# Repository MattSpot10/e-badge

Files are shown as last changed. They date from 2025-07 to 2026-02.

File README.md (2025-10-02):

# eBadge

**eBadge** is a customizable, hackable electronics badge designed for students to explore, build, and learn throughout their academic journey. It’s more than just a badge—it's a personal electronics lab, wearable project canvas, and long-term learning tool.

## Features

- Custom PCB with microcontroller 
- Modular peripherals: LEDs, sensors, buttons, displays, etc.
- Fully programmable with open-source firmware
- Designed for learning — from blinking LEDs to building full apps
- Battery-powered & portable — perfect for hacking on the go

## What’s in This Repo?

```bash
e-badge/
├── docs/           # Project documentation, setup guides, and images
├── hardware/       # Schematics, PCB layouts, BOMs, and 3D models
├── firmware/       # Embedded code for the badge's microcontroller
├── software/       # Host-side apps, test tools, or configurators
├── assets/         # Logos, badge graphics, and artwork
├── test/           # Scripts for testing hardware and firmware
├── LICENSE-CODE
├── LICENSE-HARDWARE
├── LICENSE-DOCS
├── README.md
└── .gitignore
```
## License

- **Hardware** – [CERN-OHL-S v2.0](./LICENSE-HARDWARE)
- **Firmware/Code** – [MIT License](./LICENSE-CODE)
- **Docs & Assets** – [CC BY-SA 4.0](./LICENSE-DOCS)

## Contributors

- Nathan Jack (jackn@byui.edu)
- Lynn Watson (watsonl@byui.edu)
- Jason Allred (allredjas@byui.edu)
- Richard Grimmett (grimmettr@byui.edu)
- Carl Gibbons (gibbonsc@byui.edu)
- Craig Lindstrom (lindstromc@byui.edu)
- Gary Godderidge (godderidgeg@byui.edu)
- Matt Manley (manleym@byui.edu)

# TODO (Senior project, delete when done)
- Fix screen connector
	- Use LCSC part C11086

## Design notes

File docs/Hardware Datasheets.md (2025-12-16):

| Part | Part Value | Datasheet link |
|---|---|---|
| Accelormeter | MMA8452QR1_C11360 | [Link](https://lcsc.com/datasheet/lcsc_datasheet_2405281404_NXP-Semicon-MMA8452QR1_C11360.pdf) |
| Buzzer | MLT-5020 | [Link](https://lcsc.com/datasheet/lcsc_datasheet_2410121451_Jiangsu-Huaneng-Elec-MLT-5020_C94598.pdf) |
| Charging Manager | TP4056 | [Link](https://www.lcsc.com/datasheet/lcsc_datasheet_1809261820_TOPPOWER-Nanjing-Extension-Microelectronics-TP4056-42-ESOP8_C16581.pdf) |
| MCU | ESP32-S3-Mini-1-N8  | [Link](https://www.espressif.com/sites/default/files/documentation/esp32-s3-mini-1_mini-1u_datasheet_en.pdf) |
| Joystick | 2765 | [Link](https://www.adafruit.com/product/2765) |
| RGB LED | RS-3535MWAM | [Link](https://lcsc.com/datasheet/lcsc_datasheet_2410121728_Foshan-NationStar-Optoelectronics-RS-3535MWAM_C842778.pdf) |
| SD Card | TF PUSH | [Link](https://lcsc.com/datasheet/lcsc_datasheet_2504101957_SHOU-HAN-TF-PUSH_C393941.pdf) |
| USB-Serial Chip  | CP2102N-A02-GQFN28R | [Link](https://lcsc.com/datasheet/lcsc_datasheet_2304140030_SKYWORKS-SILICON-LABS-CP2102N-A02-GQFN28R_C964632.pdf) |
| Adressable LEDs  | C22371528 | [Link](https://item.szlcsc.com/datasheet/WS2813B-2121/23859548.html) |

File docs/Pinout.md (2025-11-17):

## Pinout for BYUI e-Badge V3.0

| Name | No. | Type  | In Use | Description | Full Function List |
|---|---|---|---|---|---|
| GND | 1,2,42,43,46-65 | P | | | GND |
| 3V3 | 3 | P | | | Powersupply |
| IO0 | 4 | I/O/T |  Y | Strapping | RTC_GPIO0, GPIO0 |
| IO1 | 5 | I/O/T |  X | Joystick X  | RTC_GPIO1, GPIO1,TOUCH1,ADC1_CH0 |
| IO2 | 6 | I/O/T |  X | Joystick Y  | RTC_GPIO2, GPIO2,TOUCH2,ADC1_CH1 |
| IO3 | 7 | I/O/T |  X | Strapping; SD CS | RTC_GPIO3, GPIO3,TOUCH3,ADC1_CH2 |
| IO4 | 8 | I/O/T |  Y | B LED | RTC_GPIO4, GPIO4,TOUCH4,ADC1_CH3 |
| IO5 | 9 | I/O/T |  Y | G LED | RTC_GPIO5, GPIO5,TOUCH5,ADC1_CH4 |
| IO6 | 10 | I/O/T |  Y | R LED | RTC_GPIO6, GPIO6,TOUCH6,ADC1_CH5 |
| IO7 | 11 | I/O/T |  Y | Addr LEDs | RTC_GPIO7, GPIO7,TOUCH7,ADC1_CH6 |
| IO8 | 12 | I/O/T |  Y | Minibadge CLK | RTC_GPIO8, GPIO8,TOUCH8,ADC1_CH7,SUBSPICS1 |
| IO9 | 13 | I/O/T |  X | Display CS  | RTC_GPIO9, GPIO9,TOUCH9,ADC1_CH8,FSPIHD,SUBSPIHD |
| IO10 | 14 | I/O/T |  X | SPI2 MISO | RTC_GPIO10, GPIO10,TOUCH10,ADC1_CH9,FSPICS0,FSPIIO4, SUBSPICS0 |
| IO11 | 15 | I/O/T |  X | SPI2 MOSI | RTC_GPIO11, GPIO11,TOUCH11,ADC2_CH0,FSPID,FSPIIO5,SUBSPID |
| IO12 | 16 | I/O/T |  X | SPI2 CLK | RTC_GPIO12, GPIO12,TOUCH12,ADC2_CH1,FSPICLK,FSPIIO6, SUBSPICLK |
| IO13 | 17 | I/O/T |  X | Display DC  | RTC_GPIO13, GPIO13,TOUCH13,ADC2_CH2,FSPIQ,FSPIIO7,SUBSPIQ |
| IO14 | 18 | I/O/T |  Y | L | RTC_GPIO14, GPIO14,TOUCH14,ADC2_CH3,FSPIWP,FSPIDQS, SUBSPIWP |
| IO15 | 19 | I/O/T |  Y | R | RTC_GPIO15, GPIO15,U0RTS,ADC2_CH4,XTAL_32K_P |
| IO16 | 20 | I/O/T |  Y | D | RTC_GPIO16, GPIO16,U0CTS,ADC2_CH5,XTAL_32K_N |
| IO17 | 21 | I/O/T |  Y | U | RTC_GPIO17, GPIO17,U1TXD,ADC2_CH6 |
| IO18 | 22 | I/O/T |  Y | B | RTC_GPIO18, GPIO18,U1RXD,ADC2_CH7,CLK_OUT3 |
| IO19 | 23 | I/O/T |  X | USB- | RTC_GPIO19,GPIO19,U1RTS,ADC2_CH8,CLK_OUT2, USB_D- |
| IO20 | 24 | I/O/T |  X | USB+ | RTC_GPIO20,GPIO20,U1CTS,ADC2_CH9,CLK_OUT1, USB_D+ |
| IO21 | 25 | I/O/T |  X | I2C SCL | RTC_GPIO21, GPIO21 |
| IO26^{b} | 26 | I/O/T |  X | SPI FLASH | SPICS1, GPIO26 |
| IO47 | 27 | I/O/T |  X | I2C SDA | SPICLK_P_DIFF, GPIO47,SUBSPICLK_P_DIFF |
| IO33 | 28 | I/O/T |  X | SPI FLASH | SPIIO4, GPIO33,FSPIHD,SUBSPIHD |
| IO34 | 29 | I/O/T |  X | SPI FLASH | SPIIO5, GPIO34,FSPICS0,SUBSPICS0 |
| IO48 | 30 | I/O/T |  X | Display RST | SPICLK_N_DIFF, GPIO48,SUBSPICLK_N_DIFF |
| IO35 | 31 | I/O/T |  X | SPI FLASH | SPIIO6, GPIO35,FSPID,SUBSPID |
| IO36 | 32 | I/O/T |  X | SPI FLASH | SPIIO7, GPIO36,FSPICLK,SUBSPICLK |
| IO37 | 33 | I/O/T |  X | SPI FLASH | SPIDQS, GPIO37,FSPIQ,SUBSPIQ |
| IO38 | 34 | I/O/T |  Y | A | GPIO38,FSPIWP,SUBSPIWP |
| IO39 | 35 | I/O/T |  X | JTAG | MTCK,GPIO39,CLK_OUT3,SUBSPICS1 |
| IO40 | 36 | I/O/T |  X | JTAG | MTDO,GPIO40,CLK_OUT2 |
| IO41 | 37 | I/O/T |  X | JTAG; C LED | MTDI,GPIO41,CLK_OUT1 |
| IO42 | 38 | I/O/T |  X | JTAG; Buzzer| MTMS,GPIO42 |
| TXD0 | 39 | I/O/T |  X | UART | U0TXD,GPIO43,CLK_OUT1 |
| RXD0 | 40 | I/O/T |  X | UART | U0RXD,GPIO44,CLK_OUT2 |
| IO45 | 41 | I/O/T |  X | Strapping | GPIO45 |
| IO46 | 44 | I/O/T |  X | Strapping | GPIO46 |
| EN | 45 | I | | | High:on,enablesthechip. <br> Low:off,thechippowersoff. <br> Note:DonotleavetheENpinfloating. |

b For modules with ordering codes ending with -N4R2, IO26 connects to the embedded PSRAM and is not
available for other uses
<br>Y = taken
<br>X = Taken, but exposed



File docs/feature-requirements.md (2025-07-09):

# eBadge Featureset

### MCU Features
* Wi-Fi/Bluetooth Capable
* JTAG single step debugging
* Dual Core (Defaults to Single Core)
* Supports MicroPython, Arduino IDE and RTOS!

### On-board Peripherals
* SPI Multicolor Screen (refresh >= 30 Hz)
* 6X Buttons with pull-down resistor configuration
* 2 LEDs
* 1 Tri-colored LED
* Speaker
* SD Card Slot
* Open slot of analog stick from Adafruit

### Interfaces
* 4pin JST SH/Grove/Stemma Connector 
* 4pin JST PH/mini-grove/Stemma QT connector
* 2X Minibadge Connectors
* 9X genereic Female Headers
* 10X exposed multipurpose pins

### Additional Features
* Detailed Silk Screen
* Battery hook in + charging circuitry
* Accelerometer

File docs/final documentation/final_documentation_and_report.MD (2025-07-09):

# BYU-Idaho Dev Board Badge  
**Senior Capstone Project – ECEN 499 S25**

## Team Members  
- **Carson Bush** – [bus21005@byui.edu](mailto:bus21005@byui.edu)  
- **Getu Keno** – [haw16019@byui.edu](mailto:haw16019@byui.edu)  
- **Ammon Edwards** – [edw20012@byui.edu](mailto:edw20012@byui.edu)  
- **Danny Tolman** – [ken17002@byui.edu](mailto:ken17002@byui.edu)  
- **Everett Buttars** – [tol21004@byui.edu](mailto:tol21004@byui.edu)

## Faculty Sponsors  
- **Matt Manley (Lead)** – BYUI CSE Dept – [manleym@byui.edu](mailto:manleym@byui.edu)  
- **Jason Allred** – BYUI CSE Dept – [allredjas@byui.edu](mailto:allredjas@byui.edu)  
- **Richard Grimmett** – BYUI CSE Dept – [grimmettr@byui.edu](mailto:grimmettr@byui.edu)  
- **Lynn Watson** – BYUI CSE Dept – [watsonl@byui.edu](mailto:watsonl@byui.edu)  
- **Nathan Jack** – BYUI CSE Dept – [nathanjack@byui.edu](mailto:nathanjack@byui.edu)

## Project Repository Overview  
This repository contains all design files, documentation, and resources for the BYU-Idaho Dev Board Badge senior project. The board is a wearable, student-focused development platform designed for educational use across the Electrical and Computer Engineering and Computer Science programs.

### Key Features  
- Wearable Minibadge-compatible form factor  
- Support for both C and MicroPython environments  
- Designed for multi-semester reuse  
- Educational ecosystem compatibility (Grove, STEMMA, SAO)  
- Rechargeable battery support with USB-C charging  
- Standards-based I²C, SPI, and USB interfaces

---

## Included in This Repository  

### 📁 Final Deliverables  
- Final Written Report (with Bill of Materials)  
- Final Oral Presentation – Slides & Video  
- Final Project Poster  
- Executive Summaries  
- Weekly Progress Reports (WIGs)

### 📁 Design Files  
- KiCad Schematic & PCB Layout  
- Pinout Diagram  
- 3D Board Render (optional)  
- Firmware Prototypes (MicroPython / C)  
- Machine Learning Data & Code (Tomato Classification Project)  
- RGB LED Control Documentation

### 📁 Testing & Validation  
- Testing Code  
- Demonstration Scripts  
- Data Analysis Tools

---

## Usage Notes  
To properly view relative file links and embedded diagrams, open this repository in a Markdown-rendering environment (such as GitHub, GitLab, or a Markdown viewer). For local file viewing, Chrome or Firefox are recommended. **Do not use Edge**, as it does not reliably resolve local relative paths.

---

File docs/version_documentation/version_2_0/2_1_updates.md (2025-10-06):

# Version 2.1 Updates

<details>
<summary>Buzzer Circuitry Fix</summary>
<br>

The buzzer circuitry went straight into the GPIO pin.
</details>

<details>
<summary>Green LED Flashing</summary>
<br>
</details>

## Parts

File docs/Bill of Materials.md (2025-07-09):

| Datasheet | On Board Reference | Qty | Value | Footprint |
| --- | --- | --- | --- | --- |
| [Piezo Buzzer](https://lcsc.com/product-detail/Buzzers_MLT-5020_C94598.html) | BUZZER1 | 1 | MLT-5020 | lcsc-lib:BUZ-SMD_L5.0-W5.5-P4.60 |
| [Cap](https://www.lcsc.com/datasheet/lcsc_datasheet_2304140030_Samsung-Electro-Mechanics-CL10A106MA8NRNC_C96446.pdf) | C1,C5,C6,C7,C12,C13 | 6 | 10uF | PCM_JLCPCB:C_0603 |
| [Cap](https://www.lcsc.com/datasheet/lcsc_datasheet_2211101700_YAGEO-CC0603KRX7R9BB104_C14663.pdf) | C2,C10,C11,C14,C24,C25  | 6 | 100nF | PCM_JLCPCB:C_0603 |
| [Cap](https://www.lcsc.com/datasheet/lcsc_datasheet_2304140030_Samsung-Electro-Mechanics-CL05A105KA5NQNC_C52923.pdf) | C3,C4,C8,C9,C15,C16,C17 | 7 | 1uF | PCM_JLCPCB:C_0402 |
| [Cap](https://www.lcsc.com/datasheet/lcsc_datasheet_2304140030_Samsung-Electro-Mechanics-CL10A105KB8NNNC_C15849.pdf) | C18,C19,C20,C21,C22,C23 | 6 | 1uF | PCM_JLCPCB:C_0603 |
| [Cap](https://www.lcsc.com/datasheet/lcsc_datasheet_2304140030_Samsung-Electro-Mechanics-CL10A475KO8NNNC_C19666.pdf) | C26 | 1 | 4.7uF | PCM_JLCPCB:C_0603 |
| [SD Card](https://lcsc.com/product-detail/Connector-Card-Sockets_SHOU-HAN-SHOU-HAN-TFDeck-TF-Deck_C393941.html) | SD Card | 1 | TF PUSH | lcsc-lib:TF-SMD_TF-PUSH |
| [JST PH](https://lcsc.com/product-detail/_JST_B4B-PH-SM4-TB-LF-SN_B4B-PH-SM4-TB-LF-SN_C160354.html) | CN1 | 1 | B4B-PH-SM4-TB (LF)(SN) | lcsc-lib:CONN-SMD_B4B-PH-SM4-TB-LF-SN |
| [Red LED](https://www.lcsc.com/datasheet/lcsc_datasheet_1810231112_Hubei-KENTO-Elec-KT-0603R_C2286.pdf) | D1,D10 | 2 | Red | PCM_JLCPCB:D_0603 |
| [Surge Protector](https://lcsc.com/product-detail/New-Arrivals_Leshan-Radio-LESD5D5-0CT1G_C383211.html) | D2,D3,D4,D6,D7,D8 | 6 | LESD5D5.0CT1G | lcsc-lib:SOD-523_L1.2-W0.8-LS1.6-BI |
| [Schottky](https://wmsc.lcsc.com/wmsc/upload/file/pdf/v2/lcsc/2308281443_hongjiacheng-B0520W_C7502707.pdf) | D5,D9,D11 | 3 | B0520W | PCM_JLCPCB:D_SOD-123 |
| [LED](https://www.lcsc.com/datasheet/lcsc_datasheet_1806151820_Hubei-KENTO-Elec-KT-0805G_C2297.pdf) | D12 | 1 | Green | PCM_JLCPCB:D_0805 |
| [USB-C](https://atta.szlcsc.com/upload/public/pdf/source/20220920/0EF8F885FCCEA71F60E9E85152155021.pdf) | J1,J2 | 2 | Connector, USB-TYPE-C-16P | PCM_JLCPCB:TYPE-C-SMD_HX-TYPE-C-16PIN |
| [Ribbon Cable](https://www.lcsc.com/datasheet/lcsc_datasheet_2504101957_JUSHUO-AFC01-S12FCA-00_C262661.pdf) | J3 | 1 | ~ | lcsc-lib:FPC-SMD_AFC01-S12FCA-00 |
| [RGB LED](https://lcsc.com/product-detail/Light-Emitting-Diodes-LED_Foshan-NationStar-Optoelectronics-RS-3535MWAM_C842778.html) | LED1 | 1 | RS-3535MWAM | lcsc-lib:LED-ARRAY-SMD_L3.7-W3.5-P1.10-TL |
| [Mini-Badge*](https://github.com/BYU-I-eBadge/minibadge/blob/master/README.md) | MB1,MB2 | 2 | MiniBadge_Full | minibadge:MiniBadge_Full_NoEdges |
| [Battery JST PH](https://lcsc.com/product-detail/PH-Connectors_PH-2A_C2319.html) | P1 | 1 | PH-2A_C2319 | lcsc-lib:CONN-TH_2P-P2.00_PH-2A_C2319 |
| [Transistor](https://www.lcsc.com/datasheet/lcsc_datasheet_2303221100_Jiangsu-Changjing-Electronics-Technology-Co---Ltd--SS8050-RANGE-200-350_C2150.pdf) | Q1,Q2 | 2 | SS8050 200-350 | PCM_JLCPCB:Q_SOT-23 |
| [MOSFET](https://wmsc.lcsc.com/wmsc/upload/file/pdf/v2/lcsc/2308281515_hongjiacheng-HL2301A_C7420344.pdf) | Q3 | 1 | HL2301A | PCM_JLCPCB:Q_SOT-23 |
| [Resistor](https://www.lcsc.com/datasheet/lcsc_datasheet_2206010216_UNI-ROYAL-Uniroyal-Elec-0402WGF0000TCE_C17168.pdf) | R1,R11,R12,R15,R16 | 5 | 0Ω | PCM_JLCPCB:R_0402 |
| [Resistor](https://www.lcsc.com/datasheet/lcsc_datasheet_2206010045_UNI-ROYAL-Uniroyal-Elec-0402WGF5101TCE_C25905.pdf) | R2,R3,R4,R5,R6,R19 | 6 | 5.1kΩ | PCM_JLCPCB:R_0402 |
| [Resistor](https://www.lcsc.com/datasheet/lcsc_datasheet_2206010100_UNI-ROYAL-Uniroyal-Elec-0402WGF2202TCE_C25768.pdf) | R7 | 1 | 22kΩ | PCM_JLCPCB:R_0402 |
| [Resistor](https://www.lcsc.com/datasheet/lcsc_datasheet_2206010100_UNI-ROYAL-Uniroyal-Elec-0402WGF4702TCE_C25792.pdf) | R8 | 1 | 47kΩ | PCM_JLCPCB:R_0402 |
| [Resistor](https://www.lcsc.com/datasheet/lcsc_datasheet_2206010216_UNI-ROYAL-Uniroyal-Elec-0402WGF1001TCE_C11702.pdf) | R9,R25 | 2 | 1kΩ | PCM_JLCPCB:R_0402 |
| [Resistor](https://www.lcsc.com/datasheet/lcsc_datasheet_2411221126_UNI-ROYAL-Uniroyal-Elec-0402WGF1002TCE_C25744.pdf) | R10,R13,R14,R17 | 4 | 10kΩ | PCM_JLCPCB:R_0402 |
| [Resistor](https://www.lcsc.com/datasheet/lcsc_datasheet_2205311900_UNI-ROYAL-Uniroyal-Elec-0402WGF1000TCE_C25076.pdf) | R18,R20 | 2 | 100Ω | PCM_JLCPCB:R_0402 |
| [Resistor](https://www.lcsc.com/datasheet/lcsc_datasheet_2205311900_UNI-ROYAL-Uniroyal-Elec-0402WGF470JTCE_C25118.pdf) | R21,R22 | 2 | 47Ω | PCM_JLCPCB:R_0402 |
| [Potentiometer](https://lcsc.com/product-detail/Precision-Potentiometer_10KR_C118954.html) | R23 | 1 | 3296W-1-103 | lcsc-lib:RES-ADJ-TH_3P-L10.0-W10.0-P2.50-L |
| [Resistor](https://www.lcsc.com/datasheet/lcsc_datasheet_2206010100_UNI-ROYAL-Uniroyal-Elec-0402WGF1003TCE_C25741.pdf) | R24 | 1 | 100kΩ | PCM_JLCPCB:R_0402 |
| [Resistor](https://www.lcsc.com/datasheet/lcsc_datasheet_2206010045_UNI-ROYAL-Uniroyal-Elec-0402WGF2201TCE_C25879.pdf) | R26 | 1 | 2.2kΩ | PCM_JLCPCB:R_0402 |
| [Resistor](https://www.lcsc.com/datasheet/lcsc_datasheet_2206010045_UNI-ROYAL-Uniroyal-Elec-0603WAF1002T5E_C25804.pdf) | R27-R38 | 12  | 10kΩ | PCM_JLCPCB:R_0603 |
| [Resistor](https://www.lcsc.com/datasheet/lcsc_datasheet_2206010116_UNI-ROYAL-Uniroyal-Elec-0603WAF4701T5E_C23162.pdf) | R39,R40 | 2 | 4.7kΩ | PCM_JLCPCB:R_0603 |
| [Joy Stick*](https://www.adafruit.com/product/444) | S1 | 1 | 2765 | AdafruitJoystick:SW_2765 |
| [set/reset Buttons](https://lcsc.com/product-detail/Tactile-Switches_XUNPU-TS-1088-AR02016_C720477.html) | SW1,SW2 | 2 | TS-1088-AR02016 | lcsc-lib:SW-SMD_L3.9-W3.0-P4.45 |
| [On/Off Switch](https://lcsc.com/product-detail/Slide-Switches_G-Switch-MK-12C02-G020_C963206.html) | SW3 | 1 | SK-12F04-G050 | lcsc-lib:SW-TH_G-SWITCH_SK-12F04-G050 |
| [Push Buttons](https://lcsc.com/product-detail/Tactile-Switches_SHOU-HAN-TS665CJ_C393938.html) | SW4,SW5,SW6,SW7,SW8,SW9 | 6 | TS665CJ | lcsc-lib:SW-TH_4P-L6.0-W6.0-P4.50-LS6.5 |
| [MCU](https://www.espressif.com/sites/default/files/documentation/esp32-s3-mini-1_mini-1u_datasheet_en.pdf) | U1 | 1 | ESP32-S3-MINI-1-N8 | RF_Module:ESP32-S2-MINI-1 |
| [Voltage Regulator](https://lcsc.com/product-detail/Linear-Voltage-Regulators-LDO_onsemi-NCP167BMX330TBG_C892227.html) | U2 | 1 | NCP167BMX330TBG | lcsc-lib:XDFN-4_L1.0-W1.0-P0.65-BL-EP |
| [UART-USB](https://www.silabs.com/documents/public/data-sheets/cp2102n-datasheet.pdf) | U3 | 1 | CP2102N-A02-GQFN28R | lcsc-lib:QFN-28_L5.0-W5.0-P0.50-TL-EP3.3 |
| [Battery Charger](https://www.lcsc.com/datasheet/lcsc_datasheet_1809261820_TOPPOWER-Nanjing-Extension-Microelectronics-TP4056-42-ESOP8_C16581.pdf) | U4 | 1 | TP4056 | PCM_JLCPCB:ESOP-8_L4.9-W3.9-P1.27-LS6.0-BL-EP |
| [2 Pin Female Header](https://lcsc.com/product-detail/Female-Headers_XUNPU-FH2-54-09-02PZD_C7500771.html) | U5,U7,U10,U13,U17,U19 | 6 | FH2.54-09-02PZD | lcsc-lib:HDR-TH_2P-P2.54-V-M-5 |
| [JST-SH](https://lcsc.com/product-detail/Wire-To-Board-Connector_Megastar-ZX-SH1-0-4PWT_C7430446.html) | U6 | 1 | ZX-SH1.0-4PWT | lcsc-lib:CONN-SMD_4P-P1.00_MEGASTAR_ZX-SH1.0-4PWT |
| [3 Pin Female Header](https://lcsc.com/product-detail/Female-Headers_XUNPU-FH2-54-09-03PZD_C7500772.html) | U8,U9,U12 | 3 | FH2.54-09-03PZD | lcsc-lib:HDR-TH_3P-P2.54-V-F |
| [4 Pin Female Header](https://lcsc.com/product-detail/Female-Headers_XUNPU-FH2-54-09-03PZD_C7500772.html) | U11,U14,U15,U16 | 4 | FH2.54-09-04PZD | lcsc-lib:HDR-TH_4P-P2.54-V-F |
| [Accelerometer](https://lcsc.com/product-detail/Motion-Sensors-Accelerometers_FREESCALE_MMA8452QR1_MMA8452QR1_C11360.html) | U18 | 1 | MMA8452QR1_C11360 | lcsc-lib:QFN-16_L3.0-W3.0-P0.50-TL_MMA8452QR1 |
| | | | | |
\* Item is used for footprint and not included in final BoM

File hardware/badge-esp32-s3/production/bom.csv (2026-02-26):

Designator | Footprint | Quantity | Value | LCSC Part #
AL1, AL10, AL11, AL12, AL13, AL14, AL15, AL16, AL17, AL18, AL19, AL2, AL20, AL21, AL22, AL23, AL24, AL3, AL4, AL5, AL6, AL7, AL8, AL9 | LED-SMD_6P-L2.2-W2.2-TL-1 | 24 | ~ | C22371528
BUZZER1 | BUZ-SMD_L5.0-W5.5-P4.60 | 1 | MLT-5020 | C94598
C1, C12, C13, C5, C6, C7 | C_0603 | 6 | 10uF | C96446
C10, C11, C25, C34, C35, C36 | C_0402 | 6 | 100nF | C1525
C14, C2 | C_0603 | 2 | 100nF | C14663
C15, C16, C3, C32, C33, C4, C8, C9 | C_0402 | 8 | 1uF | C52923
C17, C27 | C0805 | 2 | 10uF
C18, C19, C20, C21, C22, C23 | C_0603 | 6 | 1uF | C15849
C26 | C_0603 | 1 | 4.7uF | C19666
C28, C37 | C0603 | 2 | TMK107BBJ106MA-T | C386081
C29, C30, C31 | C0805 | 3 | 22uF
CARD1 | TF-SMD_TF-PUSH | 1 | TF PUSH | C393941
CN1 | CONN-SMD_B4B-PH-SM4-TB-LF-SN | 1 | B4B-PH-SM4-TB (LF)(SN) | C160354
D1, D14 | D_0603 | 2 | Red | C2286
D11, D5, D9 | D_SOD-123 | 3 | B0520W | C7502707
D12 | D_0805 | 1 | Green | C2297
D13 | SMA_L4.5-W2.6-LS5.1-RD | 1 | SMAJ7.0A
D2, D3, D4, D6, D7, D8 | SOD-523_L1.2-W0.8-LS1.6-BI | 6 | LESD5D5.0CT1G | C5199850
J1, J2 | TYPE-C-SMD_HX-TYPE-C-16PIN | 2 | Connector, USB-TYPE-C-16P | C2927039
J11 | PinSocket_2x03_P2.54mm_Vertical | 1 | Conn_02x03_Odd_Even | C541853
J12, J14, J15, J5 | PinSocket_1x02_P2.54mm_Vertical | 4 | Conn_01x02_Socket | C7499322
J13, J6 | PinSocket_1x04_P2.54mm_Vertical | 2 | Conn_01x04_Socket | C2718488
J3, J9 | PinSocket_2x06_P2.54mm_Vertical | 2 | Conn_02x06_Odd_Even | C5307342
J4 | PinSocket_2x15_P2.54mm_Vertical | 1 | Conn_02x15_Odd_Even | C7499350
J7, J8 | PinSocket_1x08_P2.54mm_Vertical | 2 | Conn_01x08_Socket | C42385698
L3 | IND-SMD_L4.0-W4.0_XEL4020 | 1 | XGL4020-152MEC | C7417180
LED1 | LED-ARRAY-SMD_L3.7-W3.5-P1.10-TL | 1 | RS-3535MWAM | C842778
P1 | CONN-TH_2P-P2.00_PH-2A_C2319 | 1 | PH-2A_C2319 | C2319
P2 | FPC-SMD_12P-L11.5-W5.4-P0.50 | 1 | FPC 0.5MM 12P Pull type H2.0mm Pick up | C11086
POWER1 | SW-TH_G-SWITCH_SK-12F04-G050 | 1 | SK-12F04-G050 | C2848876
Q1, Q2 | Q_SOT-23 | 2 | SS8050 200-350 | C2150
Q3, Q4 | Q_SOT-23 | 2 | HL2301A | C7420344
Q5 | DTC114EE | 1 | DTC114E | C94400
Q6, Q7 | SC-59-3_L2.9-W1.6-P0.95-LS2.9-BR | 2 | AO3424 | C475606
R1, R11, R12 | R_0402 | 3 | 0Ω | C17168
R10, R13, R14, R17, R54 | R_0402 | 5 | 10kΩ | C25744
R15, R16 | R_0402 | 2 | 470Ω | C25117
R18, R20, R40, R47, R49, R50, R51, R52 | R_0402 | 8 | 100Ω | C25076
R19, R2, R3, R4, R5, R6 | R_0402 | 6 | 5.1kΩ | C25905
R21, R22 | R_0402 | 2 | 47Ω | C25118
R23 | JOYTICK-TH_YF16-DFL7.2-B5KO-45-10-B5KO-55--RG-A22 | 1 | YF16-FL7.2-B5KA(45-10)-R-A28 | C37323739
R24, R39, R44, R48, R53 | R_0402 | 5 | 100kΩ | C25741
R25, R9 | R_0402 | 2 | 1kΩ | C11702
R26 | R_0402 | 1 | 2.2kΩ | C25879
R27, R28, R29, R30, R31, R32, R33, R34, R35, R36, R37, R38 | R_0603 | 12 | 10kΩ | C25804
R41 | R_0402 | 1 | 150kΩ | C25755
R42 | 0402 | 1 | 27Ω
R43, R45 | R_0402 | 2 | 4.7kΩ | C25900
R46, R8 | R_0402 | 2 | 47kΩ | C25792
R7 | R_0402 | 1 | 22kΩ | C25768
RV1 | Potentiometer_Bourns_3296W_Vertical | 1 | 1000Ω | C57089
SW1, SW2 | SW-SMD_L3.9-W3.0-P4.45 | 2 | TS-1088-AR02016 | C720477
SW4, SW5, SW6, SW7, SW8, SW9 | SW-TH_4P-L6.0-W6.0-P4.50-LS6.5 | 6 | TS665CJ | C393938
U1 | ESP32-S2-MINI-1 | 1 | ESP32-S3-MINI-1-N4R2 | C3013941
U18 | QFN-16_L3.0-W3.0-P0.50-TL_MMA8452QR1 | 1 | MMA8452QR1_C11360 | C11360
U2 | VQFN-HR-15_L3.0-W2.5-P0.50-BL_TPS63070RNMR | 1 | TPS630701RNMR | C2876599
U3 | QFN-28_L5.0-W5.0-P0.50-TL-EP3.3 | 1 | CP2102N-A02-GQFN28R | C964632
U4 | ESOP-8_L4.9-W3.9-P1.27-LS6.0-BL-EP | 1 | TP4056 | C16581
U6 | CONN-SMD_4P-P1.00_MEGASTAR_ZX-SH1.0-4PWT | 1 | ZX-SH1.0-4PWT | C7430446
U8 | SOT-23-5_L2.9-W1.6-P0.95-LS2.8-BL | 1 | TLV75733PDBVR | C485517

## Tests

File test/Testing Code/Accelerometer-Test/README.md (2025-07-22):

# Library Requirements
* This test uses MMA8453_n0m1 by Noah Shibley and Michael Grant
* Found in the Arduino Library Manager via searching the name
* (Direct link to library)[https://github.com/n0m1/MMA8453_n0m1]

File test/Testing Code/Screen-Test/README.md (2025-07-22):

# Library Requirements
* This test uses Adafruit-ST7735-Library by Adafruit 
* It is heavly based on their example demo, just setup with our pins
* Found in the Arduino Library Manager via searching the name
* (Direct link to library)[https://github.com/adafruit/Adafruit-ST7735-Library]

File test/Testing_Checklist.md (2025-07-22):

| Feature | Tested | Test Code Published | Working | Issue | Resolved | Changes Pushed |
|---|---|---|---|---|---|---|
| Accelerometer | Y | Y | Y |  N | | |
| Buttons |  Y | Y | N | Y | | |
| Screen |  Y | Y | Y | Y | | |
| Buzzer | Y | Y | Y | ? | | |
| RGB Led | Y | Y | Y | ? | | |
| LED | Y | Y | Y | | | |
| Charger | | | | | | |
| Voltage Regulator | Y | Y | Y | | | |
| USB-UART JTAG | | | | | | |
| USB-UART Serial | | | | | | |
| USB-CDC JTAG | | | | | | |
| USB-CDC Serial | | | | | | |
| GPIO |  Y | Y |  Y |  Y | | |
| Joystick |  Y | Y | Y | Y | | |
| SD Card | | | | | | |
| Wifi | Y | Y | Y | Y | | |
| Blue Tooth | | | | | | |
| JST PH & SH | Y | Y | Y | Y | | |
| Mini-Badges | Y | Y | Y | Y | | |

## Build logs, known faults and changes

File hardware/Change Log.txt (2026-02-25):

Matthew Spotten 2/2/2026

DONE:
_____________________________________________________________________________________________

* Changed SD Card from SPI port to dedicated SDIO controller.
	-Used GPIO 33 through GPIO 38 for this (Previously GPIO 33-37 were thought to not be safe to use).
* Added 2x3 header breaking out GPIO 33-37 placed next to SD card.

* Rerouted AButtonMid from GPIO38 to GPIO9
* Rerouted CS from GPIO9 to GPIO3
* Fixed mini-badge footprint to includes pins on it and not just a silkscreen. 
* Added a full row of headers to the bottom of footprint connected to another header.
* Added reverse polarity protection with N-channel Mosfet
* Added SPI bus breakout next to LCD FPC connector instead of the configurable GPIO section (shorten stub traces on high speed SPI line).

TO DO:
_____________________________________________________________________________________________

Move Accelerometer closer 
Change 3V3 regulator to a more standard option maybe a sot-23.

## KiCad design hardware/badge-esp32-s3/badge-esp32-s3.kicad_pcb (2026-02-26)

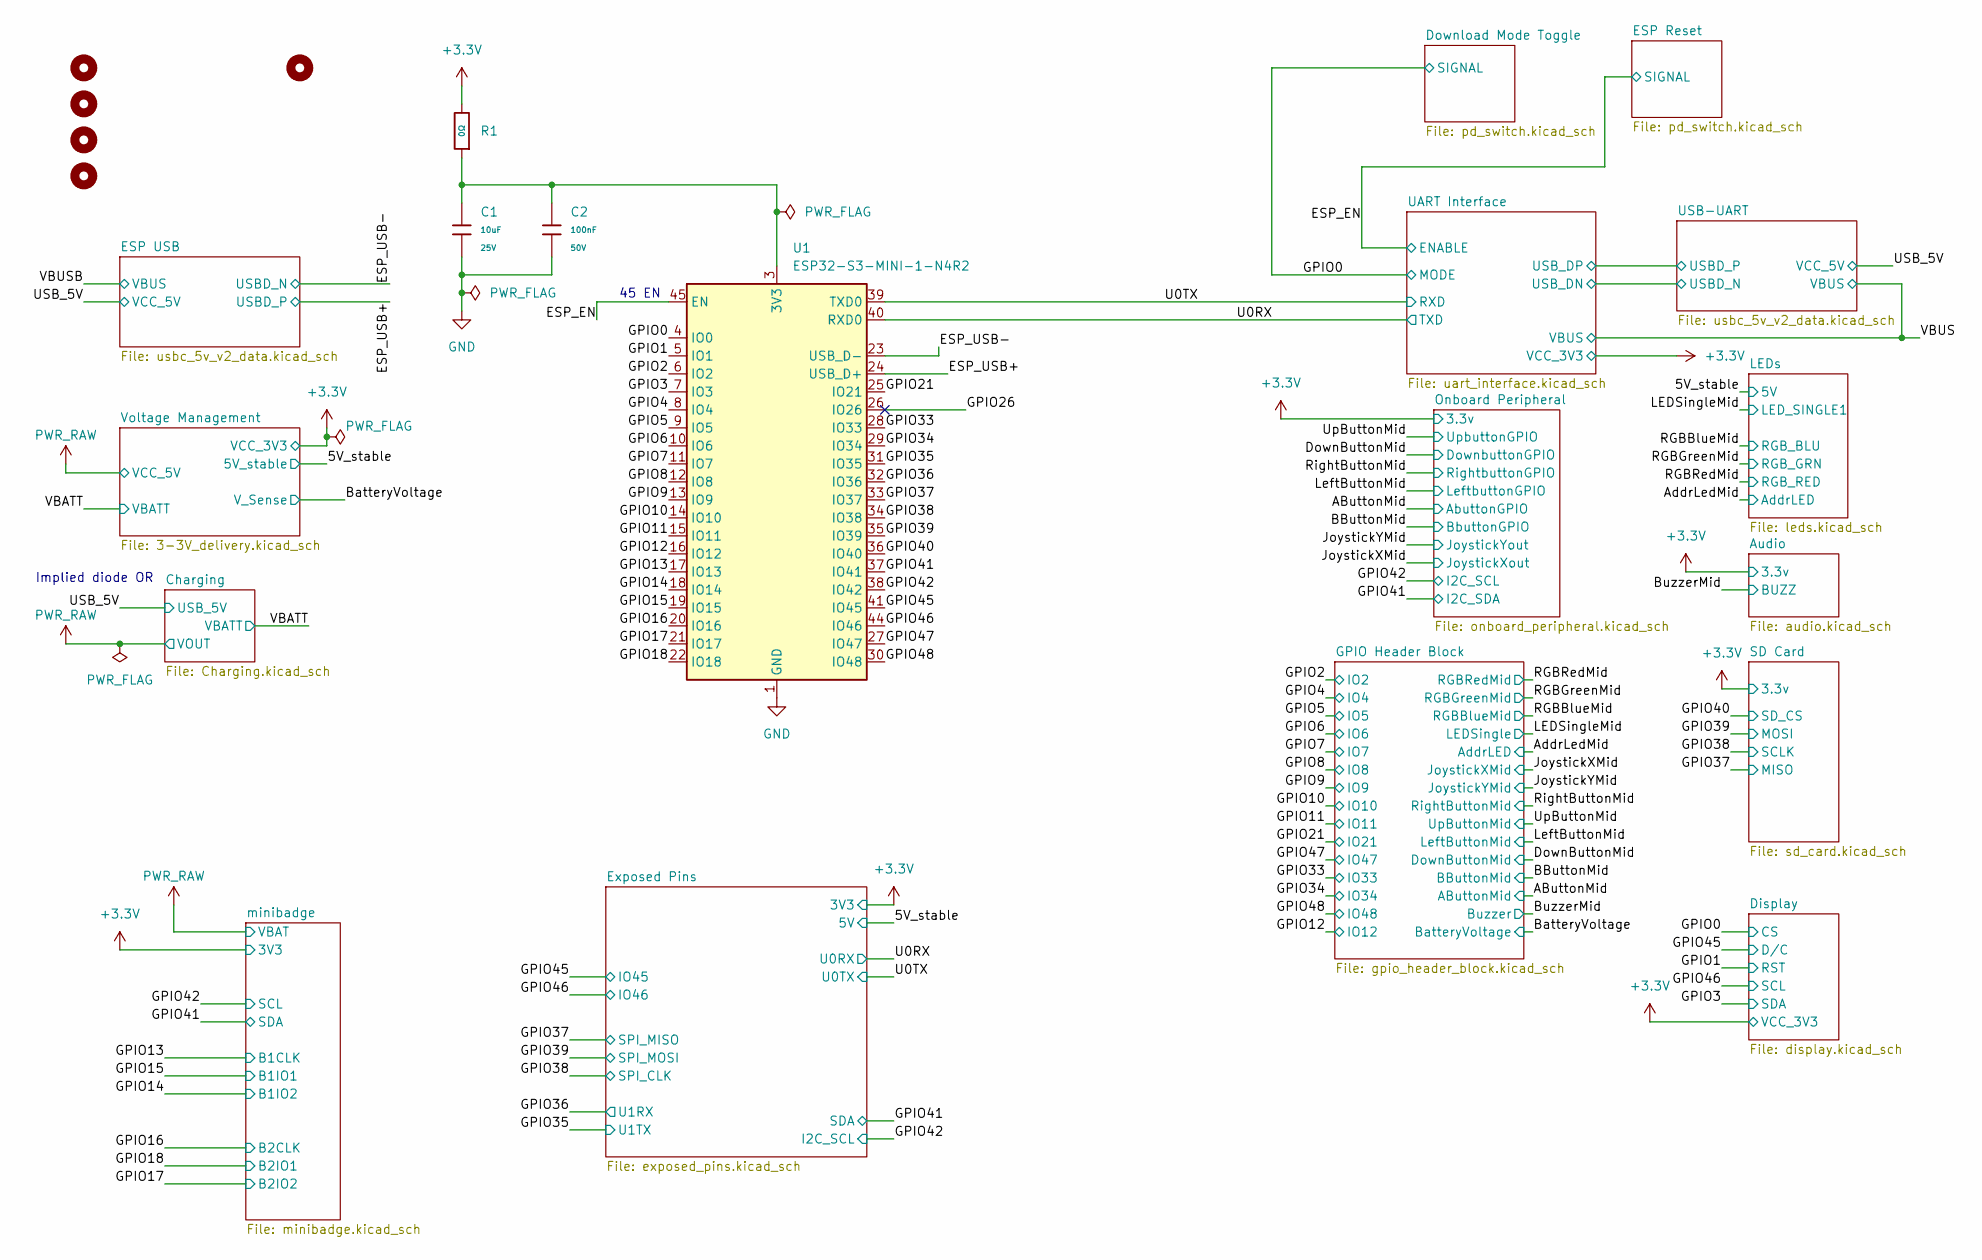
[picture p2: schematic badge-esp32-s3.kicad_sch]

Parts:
C1: 10uF; C_0603; Voltage Rated 25V; Tolerance ±20%; Part CL10A106MA8NRNC; LCSC C96446
C2: 100nF; C_0603; Voltage Rated 50V; Tolerance ±10%; Part CC0603KRX7R9BB104; LCSC C14663
H1, H2, H3, H4: MountingHole; MountingHole_3.2mm_M3_ISO7380_Pad_TopBottom
H5: MountingHole; MountingHole_5.3mm_M5
R1: 0Ω; R_0402; Overload Voltage (Max) 50V; Tolerance ±1%; Part 0402WGF0000TCE; LCSC C17168
U1: ESP32-S3-MINI-1-N4R2; ESP32-S2-MINI-1; LCSC Part C3013941

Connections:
+3.3V: R1.2; also elsewhere on the board
/ESP_EN: U1.45 (EN); also elsewhere on the board
/ESP_USB+: U1.24 (USB_D+); also elsewhere on the board
/ESP_USB-: U1.23 (USB_D-); also elsewhere on the board
/GPIO0: U1.4 (IO0); also elsewhere on the board
/GPIO1: U1.5 (IO1); also elsewhere on the board
/GPIO2: U1.6 (IO2); also elsewhere on the board
/GPIO3: U1.7 (IO3); also elsewhere on the board
/GPIO4: U1.8 (IO4); also elsewhere on the board
/GPIO5: U1.9 (IO5); also elsewhere on the board
/GPIO6: U1.10 (IO6); also elsewhere on the board
/GPIO7: U1.11 (IO7); also elsewhere on the board
/GPIO8: U1.12 (IO8); also elsewhere on the board
/GPIO9: U1.13 (IO9); also elsewhere on the board
/GPIO10: U1.14 (IO10); also elsewhere on the board
/GPIO11: U1.15 (IO11); also elsewhere on the board
/GPIO12: U1.16 (IO12); also elsewhere on the board
/GPIO13: U1.17 (IO13); also elsewhere on the board
/GPIO14: U1.18 (IO14); also elsewhere on the board
/GPIO15: U1.19 (IO15); also elsewhere on the board
/GPIO16: U1.20 (IO16); also elsewhere on the board
/GPIO17: U1.21 (IO17); also elsewhere on the board
/GPIO18: U1.22 (IO18); also elsewhere on the board
/GPIO21: U1.25 (IO21); also elsewhere on the board
/GPIO26: U1.26 (IO26)
/GPIO33: U1.28 (IO33); also elsewhere on the board
/GPIO34: U1.29 (IO34); also elsewhere on the board
/GPIO35: U1.31 (IO35); also elsewhere on the board
/GPIO36: U1.32 (IO36); also elsewhere on the board
/GPIO37: U1.33 (IO37); also elsewhere on the board
/GPIO38: U1.34 (IO38); also elsewhere on the board
/GPIO39: U1.35 (IO39); also elsewhere on the board
/GPIO40: U1.36 (IO40); also elsewhere on the board
/GPIO41: U1.37 (IO41); also elsewhere on the board
/GPIO42: U1.38 (IO42); also elsewhere on the board
/GPIO45: U1.41 (IO45); also elsewhere on the board
/GPIO46: U1.44 (IO46); also elsewhere on the board
/GPIO47: U1.27 (IO47); also elsewhere on the board
/GPIO48: U1.30 (IO48); also elsewhere on the board
/U0RX: U1.40 (RXD0); also elsewhere on the board
/U0TX: U1.39 (TXD0); also elsewhere on the board
GND: C1.2, C2.2, U1.1 (GND), U1.2 (GND), U1.42 (GND), U1.43 (GND), U1.46 (GND), U1.47 (GND), U1.48 (GND), U1.49 (GND), U1.50 (GND), U1.51 (GND), U1.52 (GND), U1.53 (GND), U1.54 (GND), U1.55 (GND), U1.56 (GND), U1.57 (GND), U1.58 (GND), U1.59 (GND), U1.60 (GND), U1.61 (GND), U1.62 (GND), U1.63 (GND), U1.64 (GND), U1.65 (GND); also elsewhere on the board
unnamed: C1.1, C2.1, R1.1, U1.3 (3V3)

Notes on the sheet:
45 EN
Implied diode OR

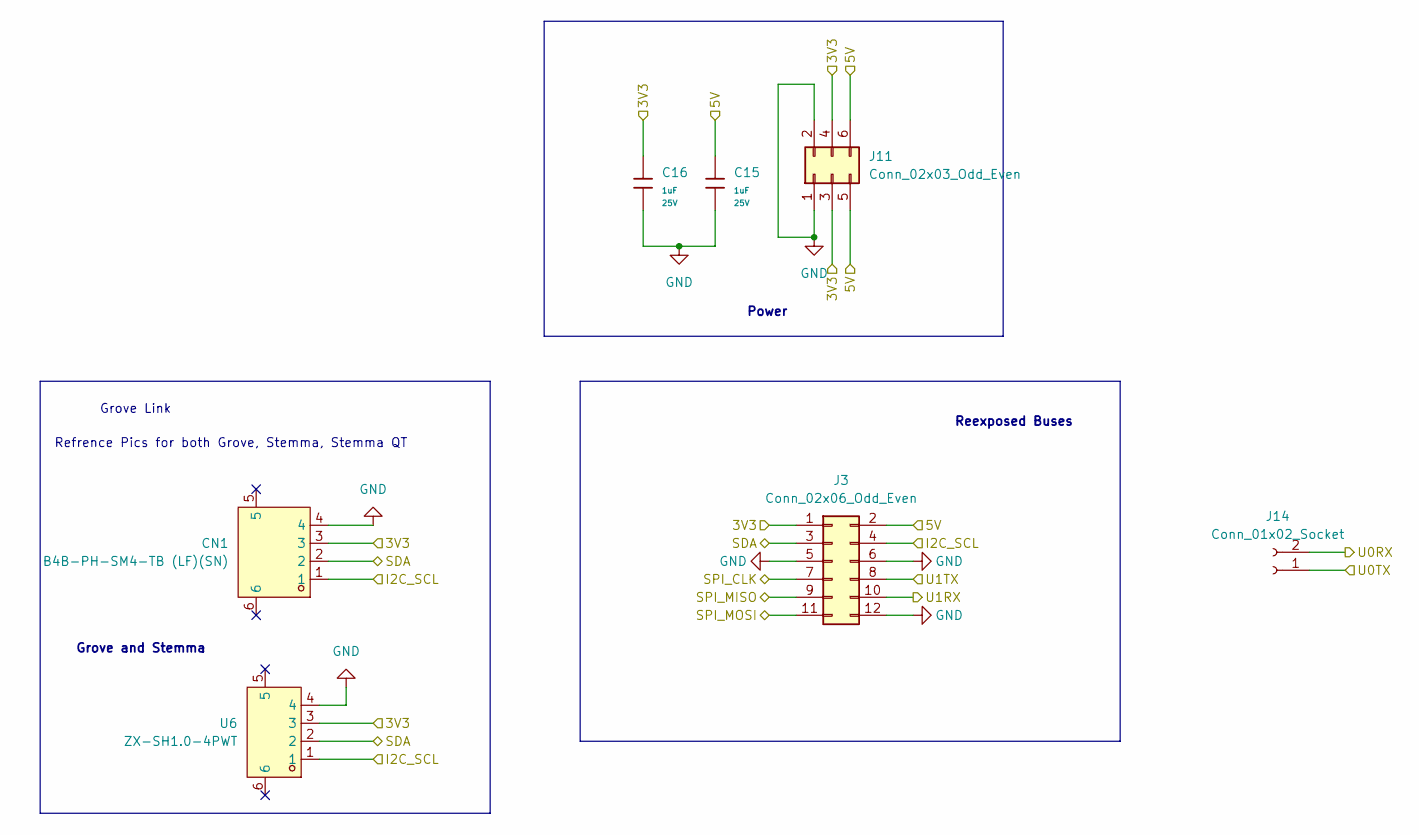
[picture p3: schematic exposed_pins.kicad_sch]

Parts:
C15, C16: 1uF; C_0402; Voltage Rated 25V; Tolerance ±10%; Part CL05A105KA5NQNC; LCSC C52923
CN1: B4B-PH-SM4-TB (LF)(SN); CONN-SMD_B4B-PH-SM4-TB-LF-SN; LCSC Part C160354
J3: Conn_02x06_Odd_Even; PinSocket_2x06_P2.54mm_Vertical; LCSC C5307342
J11: Conn_02x03_Odd_Even; PinSocket_2x03_P2.54mm_Vertical; LCSC C541853
J14: Conn_01x02_Socket; PinSocket_1x02_P2.54mm_Vertical; LCSC C7499322
U6: ZX-SH1.0-4PWT; CONN-SMD_4P-P1.00_MEGASTAR_ZX-SH1.0-4PWT; LCSC Part C7430446

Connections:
+3.3V: C16.1, CN1.3, J3.1, J11.3, J11.4, U6.3; also elsewhere on the board
/5V_stable: C15.1, J3.2, J11.5, J11.6; also elsewhere on the board
/GPIO35: J3.8; also elsewhere on the board
/GPIO36: J3.10; also elsewhere on the board
/GPIO37: J3.9; also elsewhere on the board
/GPIO38: J3.7; also elsewhere on the board
/GPIO39: J3.11; also elsewhere on the board
/GPIO41: CN1.2, J3.3, U6.2; also elsewhere on the board
/GPIO42: CN1.1, J3.4, U6.1; also elsewhere on the board
/U0RX: J14.2; also elsewhere on the board
/U0TX: J14.1; also elsewhere on the board
GND: C15.2, C16.2, CN1.4, J3.5, J3.6, J3.12, J11.1, J11.2, U6.4; also elsewhere on the board

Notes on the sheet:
Power
Reexposed Buses
Refrence Pics for both Grove, Stemma, Stemma QT
Grove Link
Grove and Stemma

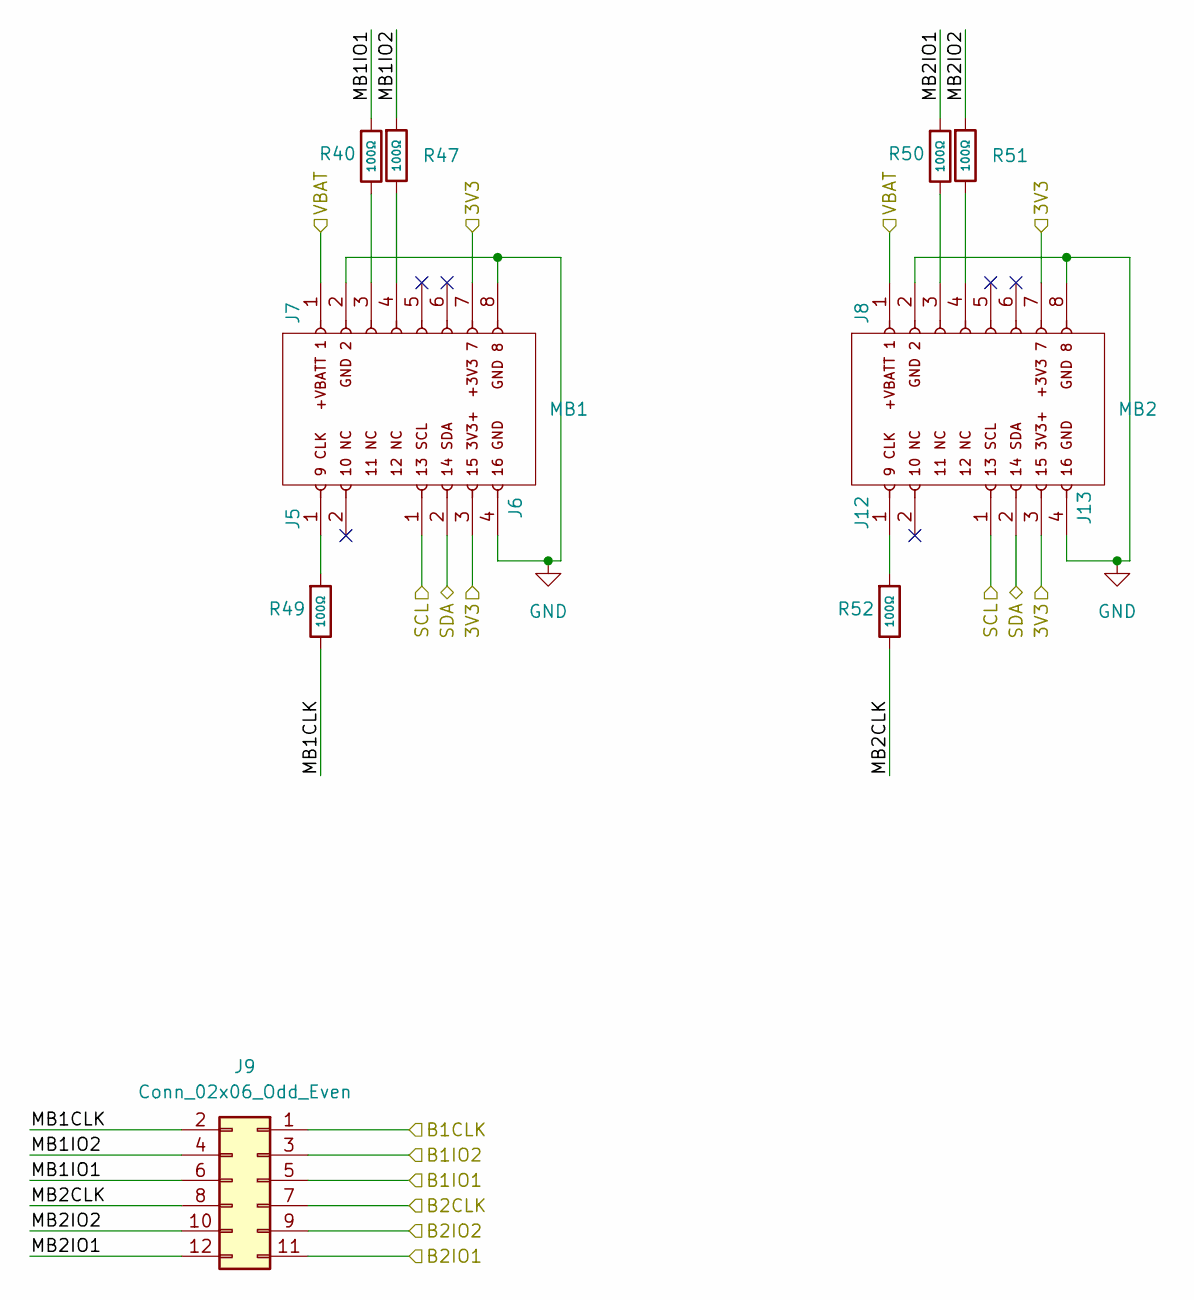
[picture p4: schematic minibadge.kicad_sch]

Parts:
J5, J12: Conn_01x02_Socket; PinSocket_1x02_P2.54mm_Vertical; LCSC C7499322
J6, J13: Conn_01x04_Socket; PinSocket_1x04_P2.54mm_Vertical; LCSC C2718488
J7, J8: Conn_01x08_Socket; PinSocket_1x08_P2.54mm_Vertical; LCSC C42385698
J9: Conn_02x06_Odd_Even; PinSocket_2x06_P2.54mm_Vertical; LCSC C5307342
MB1, MB2: MiniBadge_Full; MiniBadge_Full_NoEdges
R40, R47, R49, R50, R51, R52: 100Ω; R_0402; Overload Voltage (Max) 50V; Tolerance ±1%; Part 0402WGF1000TCE; LCSC C25076

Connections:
+3.3V: J6.3, J7.7, J8.7, J13.3; also elsewhere on the board
/GPIO13: J9.1; also elsewhere on the board
/GPIO14: J9.3; also elsewhere on the board
/GPIO15: J9.5; also elsewhere on the board
/GPIO16: J9.7; also elsewhere on the board
/GPIO17: J9.9; also elsewhere on the board
/GPIO18: J9.11; also elsewhere on the board
/GPIO41: J6.2, J13.2; also elsewhere on the board
/GPIO42: J6.1, J13.1; also elsewhere on the board
/minibadge/MB1CLK: J9.2, R49.2
/minibadge/MB1IO1: J9.6, R40.1
/minibadge/MB1IO2: J9.4, R47.1
/minibadge/MB2CLK: J9.8, R52.2
/minibadge/MB2IO1: J9.12, R50.1
/minibadge/MB2IO2: J9.10, R51.1
GND: J6.4, J7.2, J7.8, J8.2, J8.8, J13.4; also elsewhere on the board
unnamed: J5.1, R49.1
unnamed: J7.3, R40.2
unnamed: J7.4, R47.2
unnamed: J8.3, R50.2
unnamed: J8.4, R51.2
unnamed: J12.1, R52.1
PWR_RAW: J7.1, J8.1; also elsewhere on the board

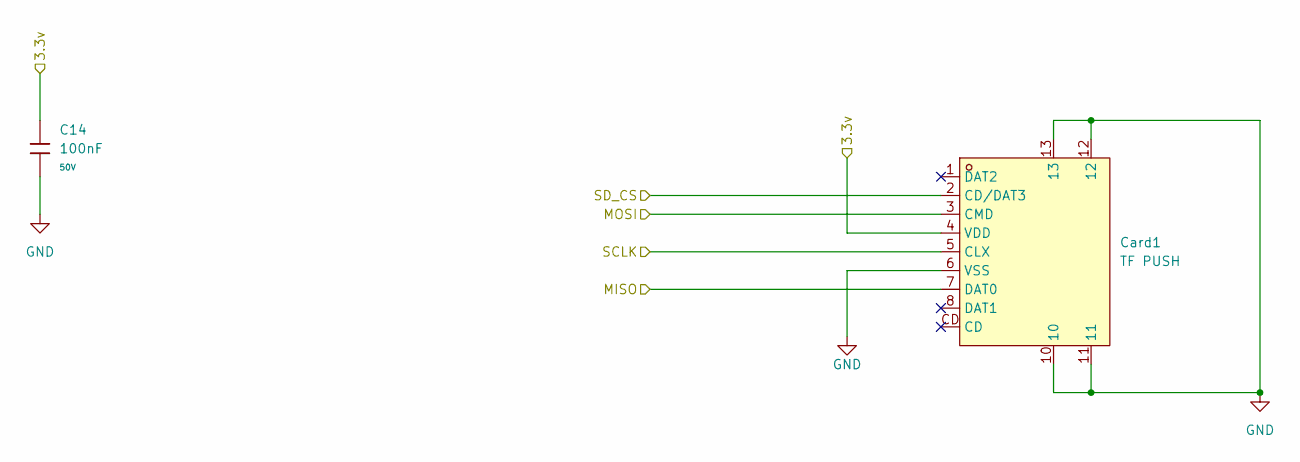
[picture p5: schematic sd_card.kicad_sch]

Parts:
C14: 100nF; C_0603; Voltage Rated 50V; Tolerance ±10%; Part CC0603KRX7R9BB104; LCSC C14663
Card1: TF PUSH; TF-SMD_TF-PUSH; LCSC Part C393941

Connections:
+3.3V: C14.1, Card1.4 (VDD); also elsewhere on the board
/GPIO37: Card1.7 (DAT0); also elsewhere on the board
/GPIO38: Card1.5 (CLX); also elsewhere on the board
/GPIO39: Card1.3 (CMD); also elsewhere on the board
/GPIO40: Card1.2 (CD/DAT3); also elsewhere on the board
GND: C14.2, Card1.6 (VSS), Card1.10, Card1.11, Card1.12, Card1.13; also elsewhere on the board

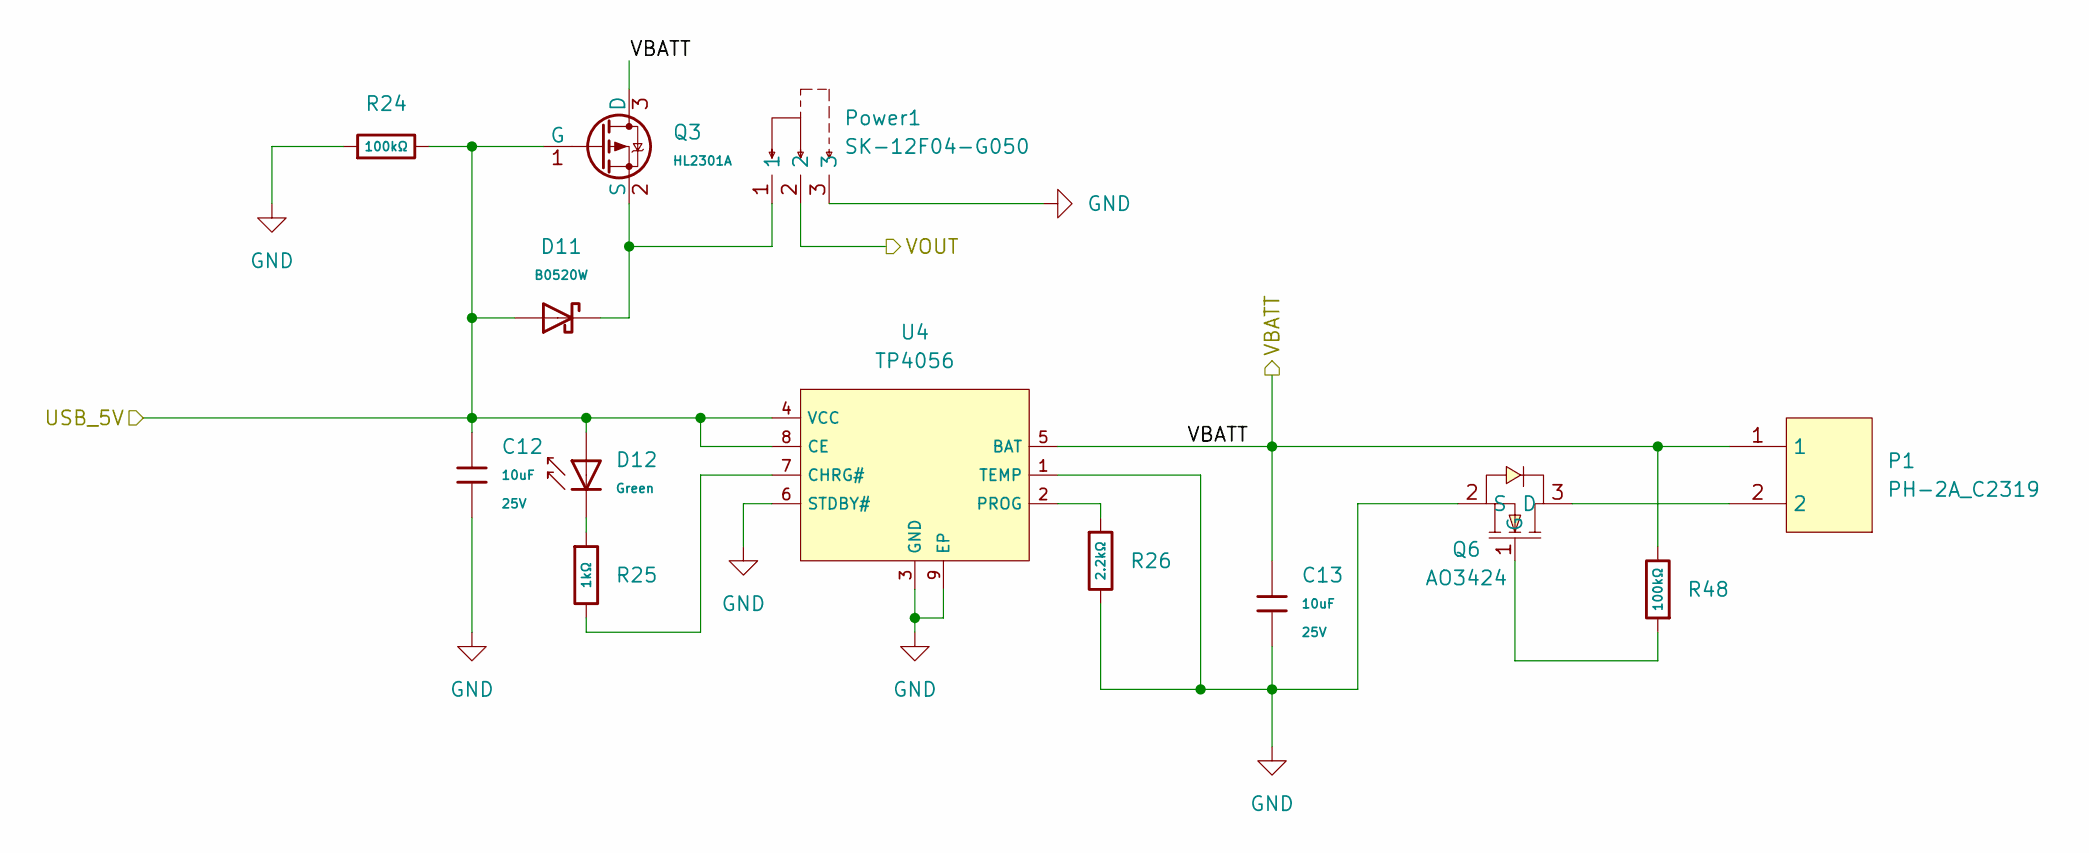
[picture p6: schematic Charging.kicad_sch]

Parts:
C12, C13: 10uF; C_0603; Voltage Rated 25V; Tolerance ±20%; Part CL10A106MA8NRNC; LCSC C96446
D11: B0520W; D_SOD-123; Part B0520W; LCSC C7502707
D12: Green; D_0805; Part KT-0805G; LCSC C2297
P1: PH-2A_C2319; CONN-TH_2P-P2.00_PH-2A_C2319; LCSC Part C2319
Power1: SK-12F04-G050; SW-TH_G-SWITCH_SK-12F04-G050; LCSC Part C2848876
Q3: HL2301A; Q_SOT-23; Part HL2301A; LCSC C7420344
Q6: AO3424; SC-59-3_L2.9-W1.6-P0.95-LS2.9-BR; LCSC Part C475606
R24, R48: 100kΩ; R_0402; Overload Voltage (Max) 50V; Tolerance ±1%; Part 0402WGF1003TCE; LCSC C25741
R25: 1kΩ; R_0402; Overload Voltage (Max) 50V; Tolerance ±1%; Part 0402WGF1001TCE; LCSC C11702
R26: 2.2kΩ; R_0402; Overload Voltage (Max) 50V; Tolerance ±1%; Part 0402WGF2201TCE; LCSC C25879
U4: TP4056; ESOP-8_L4.9-W3.9-P1.27-LS6.0-BL-EP; Part TP4056-42-ESOP8; LCSC C16581

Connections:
/USB_5V: C12.1, D11.2, D12.2, Q3.1 (G), R24.2, U4.4 (VCC), U4.8 (CE); also elsewhere on the board
/VBATT: C13.1, P1.1, Q3.3 (D), R48.2, U4.5 (BAT); also elsewhere on the board
GND: C12.2, C13.2, Power1.3, Q6.2 (S), R24.1, R26.2, U4.1 (TEMP), U4.3 (GND), U4.6 (STDBY#), U4.9 (EP); also elsewhere on the board
unnamed: D12.1, R25.1
unnamed: D11.1, Power1.1, Q3.2 (S)
unnamed: P1.2, Q6.3 (D)
unnamed: Q6.1 (G), R48.1
unnamed: R25.2, U4.7 (CHRG#)
unnamed: R26.1, U4.2 (PROG)
PWR_RAW: Power1.2; also elsewhere on the board

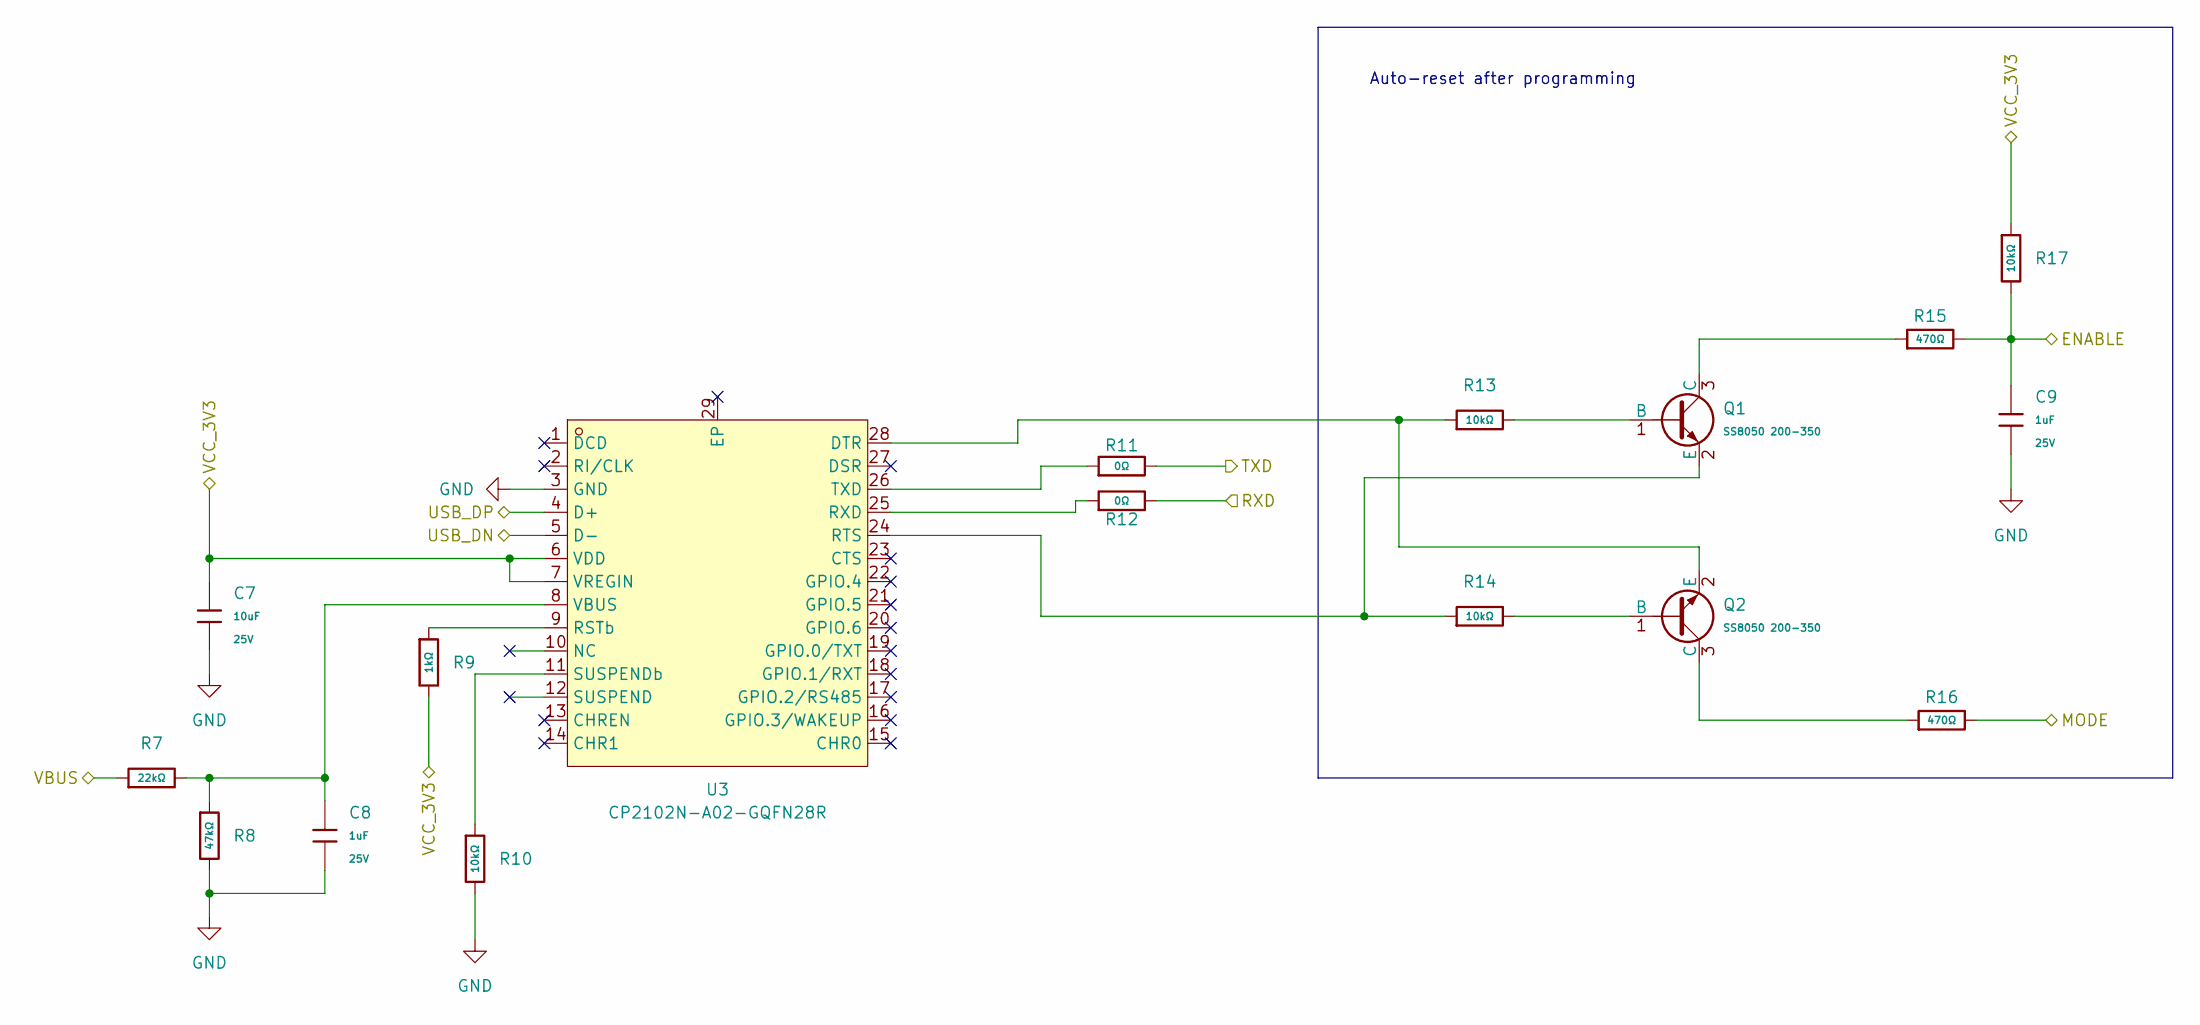
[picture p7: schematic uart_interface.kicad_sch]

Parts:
C7: 10uF; C_0603; Voltage Rated 25V; Tolerance ±20%; Part CL10A106MA8NRNC; LCSC C96446
C8, C9: 1uF; C_0402; Voltage Rated 25V; Tolerance ±10%; Part CL05A105KA5NQNC; LCSC C52923
Q1, Q2: SS8050 200-350; Q_SOT-23; Part SS8050(RANGE:200-350); LCSC C2150
R7: 22kΩ; R_0402; Overload Voltage (Max) 50V; Tolerance ±1%; Part 0402WGF2202TCE; LCSC C25768
R8: 47kΩ; R_0402; Overload Voltage (Max) 50V; Tolerance ±1%; Part 0402WGF4702TCE; LCSC C25792
R9: 1kΩ; R_0402; Overload Voltage (Max) 50V; Tolerance ±1%; Part 0402WGF1001TCE; LCSC C11702
R10, R13, R14, R17: 10kΩ; R_0402; Overload Voltage (Max) 50V; Tolerance ±1%; Part 0402WGF1002TCE; LCSC C25744
R11, R12: 0Ω; R_0402; Overload Voltage (Max) 50V; Tolerance ±1%; Part 0402WGF0000TCE; LCSC C17168
R15, R16: 470Ω; R_0402; Overload Voltage (Max) 50V; Tolerance ±1%; Part 0402WGF4700TCE; LCSC C25117
U3: CP2102N-A02-GQFN28R; QFN-28_L5.0-W5.0-P0.50-TL-EP3.3; LCSC Part C964632

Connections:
+3.3V: C7.1, R9.2, R17.1, U3.6 (VDD), U3.7 (VREGIN); also elsewhere on the board
/ESP_EN: C9.1, R15.2, R17.2; also elsewhere on the board
/GPIO0: R16.2; also elsewhere on the board
/U0RX: R11.2; also elsewhere on the board
/U0TX: R12.2; also elsewhere on the board
/UART Interface/USB_DN: U3.5 (D-); also elsewhere on the board
/UART Interface/USB_DP: U3.4 (D+); also elsewhere on the board
/VBUS: R7.1; also elsewhere on the board
GND: C7.2, C8.2, C9.2, R8.2, R10.2, U3.3 (GND); also elsewhere on the board
unnamed: Q1.1 (B), R13.2
unnamed: Q1.3 (C), R15.1
unnamed: Q1.2 (E), R14.1, U3.24 (RTS)
unnamed: Q2.1 (B), R14.2
unnamed: Q2.3 (C), R16.1
unnamed: Q2.2 (E), R13.1, U3.28 (DTR)
unnamed: R9.1, U3.9 (RSTb)
unnamed: R12.1, U3.25 (RXD)
unnamed: R10.1, U3.11 (SUSPENDb)
unnamed: R11.1, U3.26 (TXD)
unnamed: C8.1, R7.2, R8.1, U3.8 (VBUS)

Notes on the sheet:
Auto-reset after programming

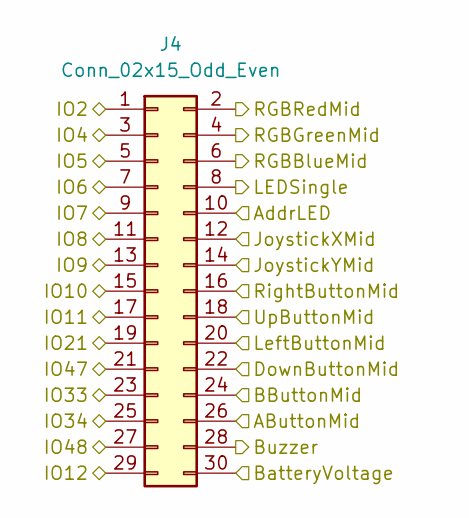
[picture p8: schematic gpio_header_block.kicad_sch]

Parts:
J4: Conn_02x15_Odd_Even; PinSocket_2x15_P2.54mm_Vertical; LCSC Part C7499350

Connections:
/AButtonMid: J4.26; also elsewhere on the board
/AddrLedMid: J4.10; also elsewhere on the board
/BButtonMid: J4.24; also elsewhere on the board
/BatteryVoltage: J4.30; also elsewhere on the board
/BuzzerMid: J4.28; also elsewhere on the board
/DownButtonMid: J4.22; also elsewhere on the board
/GPIO2: J4.1; also elsewhere on the board
/GPIO4: J4.3; also elsewhere on the board
/GPIO5: J4.5; also elsewhere on the board
/GPIO6: J4.7; also elsewhere on the board
/GPIO7: J4.9; also elsewhere on the board
/GPIO8: J4.11; also elsewhere on the board
/GPIO9: J4.13; also elsewhere on the board
/GPIO10: J4.15; also elsewhere on the board
/GPIO11: J4.17; also elsewhere on the board
/GPIO12: J4.29; also elsewhere on the board
/GPIO21: J4.19; also elsewhere on the board
/GPIO33: J4.23; also elsewhere on the board
/GPIO34: J4.25; also elsewhere on the board
/GPIO47: J4.21; also elsewhere on the board
/GPIO48: J4.27; also elsewhere on the board
/JoystickXMid: J4.12; also elsewhere on the board
/JoystickYMid: J4.14; also elsewhere on the board
/LEDSingleMid: J4.8; also elsewhere on the board
/LeftButtonMid: J4.20; also elsewhere on the board
/RGBBlueMid: J4.6; also elsewhere on the board
/RGBGreenMid: J4.4; also elsewhere on the board
/RGBRedMid: J4.2; also elsewhere on the board
/RightButtonMid: J4.16; also elsewhere on the board
/UpButtonMid: J4.18; also elsewhere on the board

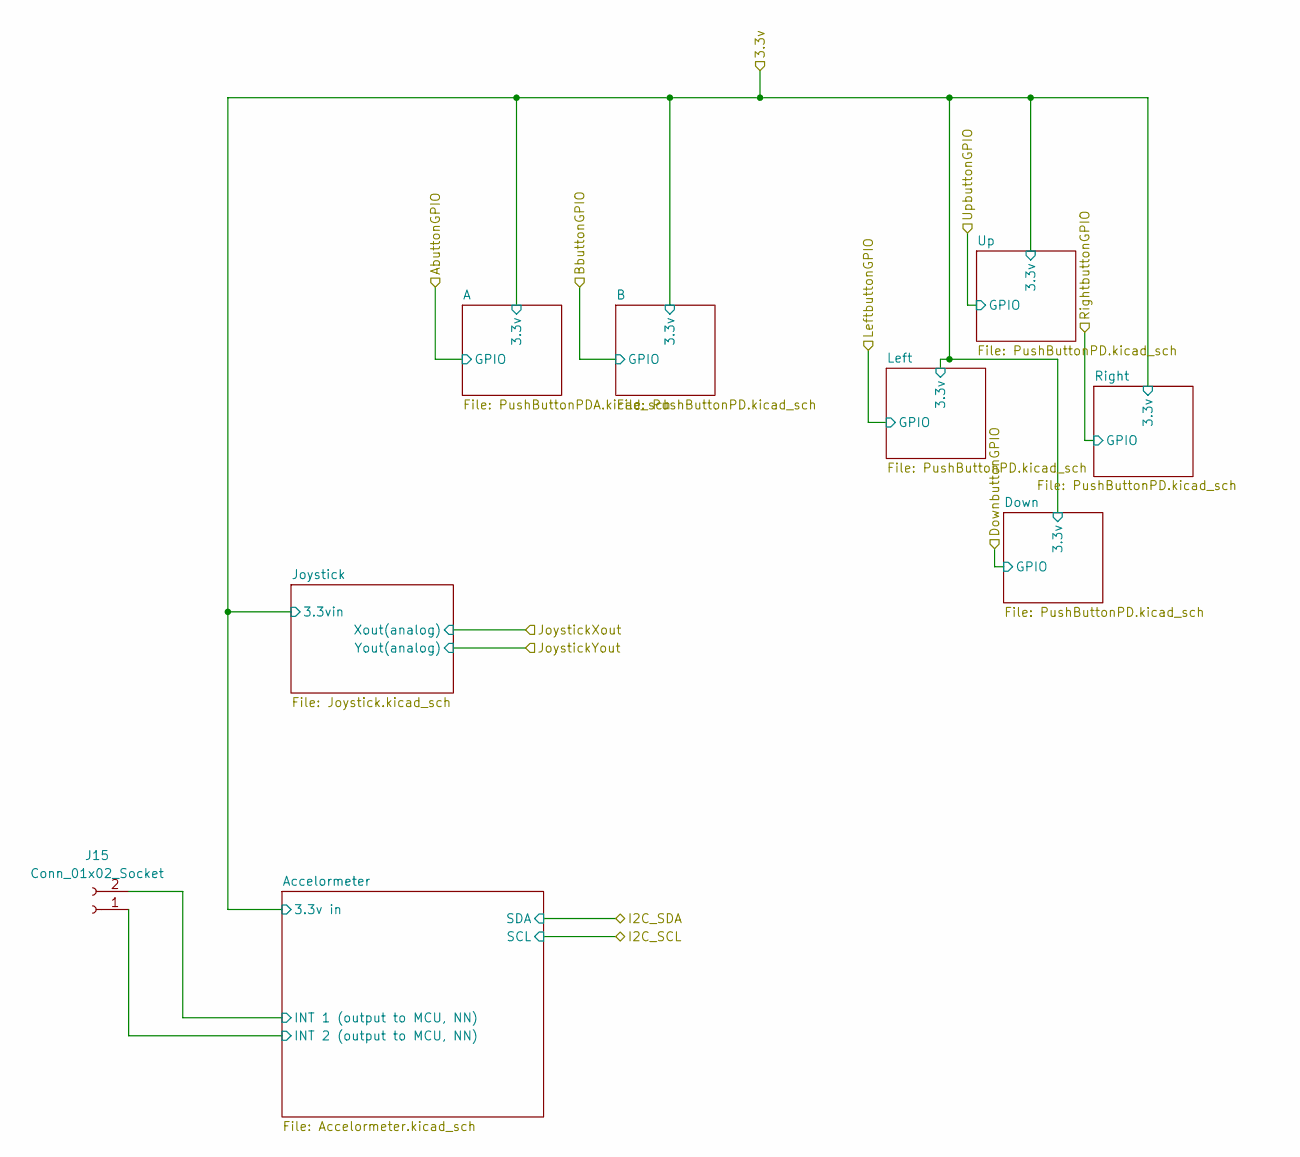
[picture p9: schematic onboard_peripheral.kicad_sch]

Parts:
J15: Conn_01x02_Socket; PinSocket_1x02_P2.54mm_Vertical; LCSC C7499322

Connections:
/Onboard Peripheral/Accelormeter/INT 1 (output to MCU, NN): J15.2; also elsewhere on the board
/Onboard Peripheral/Accelormeter/INT 2 (output to MCU, NN): J15.1; also elsewhere on the board

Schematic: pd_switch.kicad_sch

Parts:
C35: 100nF; C_0402; Voltage Rated 16V; Tolerance ±10%; Part CL05B104KO5NNNC; LCSC C1525
SW1: TS-1088-AR02016; SW-SMD_L3.9-W3.0-P4.45; LCSC Part C720477

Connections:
/GPIO0: C35.2, SW1.2; also elsewhere on the board
GND: C35.1, SW1.1; also elsewhere on the board

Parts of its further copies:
C36: 100nF; C_0402; Voltage Rated 16V; Tolerance ±10%; Part CL05B104KO5NNNC; LCSC C1525
SW2: TS-1088-AR02016; SW-SMD_L3.9-W3.0-P4.45; LCSC Part C720477

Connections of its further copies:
/ESP_EN: C36.2, SW2.2; also elsewhere on the board
GND: C36.1, SW2.1; also elsewhere on the board

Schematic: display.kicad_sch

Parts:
P2: FPC 0.5MM 12P Pull type H2.0mm Pick up; FPC-SMD_12P-L11.5-W5.4-P0.50; LCSC Part C11086
R18: 100Ω; R_0402; Overload Voltage (Max) 50V; Tolerance ±1%; Part 0402WGF1000TCE; LCSC C25076
R39: 100kΩ; R_0402; Overload Voltage (Max) 50V; Tolerance ±1%; Part 0402WGF1003TCE; LCSC C25741
TP1, TP2, TP3, TP4, TP5: TestPoint; TestPoint_Pad_D1.5mm; not fitted
U7: HS20HS072RX-fpc; OLED-SMD_HS20HS072RX-pins_removed; LCSC Part C5329582

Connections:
+3.3V: P2.8 (IOVCC), P2.9 (VCC), R18.1; also elsewhere on the board
/GPIO0: P2.2 (CS), TP1.1; also elsewhere on the board
/GPIO1: P2.6 (RST), R39.1, TP5.1; also elsewhere on the board
/GPIO3: P2.5 (SDA), TP4.1; also elsewhere on the board
/GPIO45: P2.3 (RS), TP2.1; also elsewhere on the board
/GPIO46: P2.4 (SCL), TP3.1; also elsewhere on the board
GND: P2.1 (GND), P2.11 (K), P2.12 (GND), R39.2; also elsewhere on the board
unnamed: P2.10 (A), R18.2

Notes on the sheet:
Backlight always on
Default: Reset State

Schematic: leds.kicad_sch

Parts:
AL1, AL2, AL3, AL4, AL5, AL6, AL7, AL8, AL9, AL10, AL11, AL12, AL13, AL14, AL15, AL16, AL17, AL18, AL19, AL20, AL21, AL22, AL23, AL24: LED-SMD_6P-L2.2-W2.2-TL-1; Manufacturer Part WS2813B-2121; LCSC C22371528
C32, C33: 1uF; C_0402; Voltage Rated 25V; Tolerance ±10%; Part CL05A105KA5NQNC; LCSC C52923
D14: Red; D_0603; Part KT-0603R; LCSC C2286
LED1: RS-3535MWAM; LED-ARRAY-SMD_L3.7-W3.5-P1.10-TL; LCSC Part C842778
R19: 5.1kΩ; R_0402; Overload Voltage (Max) 50V; Tolerance ±1%; Part 0402WGF5101TCE; LCSC C25905
R20: 100Ω; R_0402; Overload Voltage (Max) 50V; Tolerance ±1%; Part 0402WGF1000TCE; LCSC C25076
R21, R22: 47Ω; R_0402; Overload Voltage (Max) 50V; Tolerance ±1%; Part 0402WGF470JTCE; LCSC C25118

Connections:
/5V_stable: AL1.3 (VDD), AL2.3 (VDD), AL3.3 (VDD), AL4.3 (VDD), AL5.3 (VDD), AL6.3 (VDD), AL7.3 (VDD), AL8.3 (VDD), AL9.3 (VDD), AL10.3 (VDD), AL11.3 (VDD), AL12.3 (VDD), AL13.3 (VDD), AL14.3 (VDD), AL15.3 (VDD), AL16.3 (VDD), AL17.3 (VDD), AL18.3 (VDD), AL19.3 (VDD), AL20.3 (VDD), AL21.3 (VDD), AL22.3 (VDD), AL23.3 (VDD), AL24.3 (VDD), C32.1, C33.1; also elsewhere on the board
/AddrLedMid: AL1.2 (DI); also elsewhere on the board
/LEDSingleMid: R19.1; also elsewhere on the board
/LEDs/BO_AL9: AL9.5 (BO), AL10.1 (BI)
/LEDs/BO_AL18: AL18.5 (BO), AL19.1 (BI)
/LEDs/DO_AL9: AL9.4 (DO), AL10.2 (DI)
/LEDs/DO_AL18: AL18.4 (DO), AL19.2 (DI)
/RGBBlueMid: LED1.6 (+); also elsewhere on the board
/RGBGreenMid: LED1.5 (+); also elsewhere on the board
/RGBRedMid: LED1.4 (+); also elsewhere on the board
GND: AL1.1 (BI), AL1.6 (GND), AL2.6 (GND), AL3.6 (GND), AL4.6 (GND), AL5.6 (GND), AL6.6 (GND), AL7.6 (GND), AL8.6 (GND), AL9.6 (GND), AL10.6 (GND), AL11.6 (GND), AL12.6 (GND), AL13.6 (GND), AL14.6 (GND), AL15.6 (GND), AL16.6 (GND), AL17.6 (GND), AL18.6 (GND), AL19.6 (GND), AL20.6 (GND), AL21.6 (GND), AL22.6 (GND), AL23.6 (GND), AL24.6 (GND), C32.2, C33.2, D14.1, R20.2, R21.2, R22.2; also elsewhere on the board
unnamed: AL1.5 (BO), AL2.1 (BI)
unnamed: AL1.4 (DO), AL2.2 (DI)
unnamed: AL2.5 (BO), AL3.1 (BI)
unnamed: AL2.4 (DO), AL3.2 (DI)
unnamed: AL3.5 (BO), AL4.1 (BI)
unnamed: AL3.4 (DO), AL4.2 (DI)
unnamed: AL4.5 (BO), AL5.1 (BI)
unnamed: AL4.4 (DO), AL5.2 (DI)
unnamed: AL5.5 (BO), AL6.1 (BI)
unnamed: AL5.4 (DO), AL6.2 (DI)
unnamed: AL6.5 (BO), AL7.1 (BI)
unnamed: AL6.4 (DO), AL7.2 (DI)
unnamed: AL7.5 (BO), AL8.1 (BI)
unnamed: AL7.4 (DO), AL8.2 (DI)
unnamed: AL8.5 (BO), AL9.1 (BI)
unnamed: AL8.4 (DO), AL9.2 (DI)
unnamed: AL10.5 (BO), AL11.1 (BI)
unnamed: AL10.4 (DO), AL11.2 (DI)
unnamed: AL11.5 (BO), AL12.1 (BI)
unnamed: AL11.4 (DO), AL12.2 (DI)
unnamed: AL12.5 (BO), AL13.1 (BI)
unnamed: AL12.4 (DO), AL13.2 (DI)
unnamed: AL13.5 (BO), AL14.1 (BI)
unnamed: AL13.4 (DO), AL14.2 (DI)
unnamed: AL14.5 (BO), AL15.1 (BI)
unnamed: AL14.4 (DO), AL15.2 (DI)
unnamed: AL15.5 (BO), AL16.1 (BI)
unnamed: AL15.4 (DO), AL16.2 (DI)
unnamed: AL16.5 (BO), AL17.1 (BI)
unnamed: AL16.4 (DO), AL17.2 (DI)
unnamed: AL17.5 (BO), AL18.1 (BI)
unnamed: AL17.4 (DO), AL18.2 (DI)
unnamed: AL19.5 (BO), AL20.1 (BI)
unnamed: AL19.4 (DO), AL20.2 (DI)
unnamed: AL20.5 (BO), AL21.1 (BI)
unnamed: AL20.4 (DO), AL21.2 (DI)
unnamed: AL21.5 (BO), AL22.1 (BI)
unnamed: AL21.4 (DO), AL22.2 (DI)
unnamed: AL22.5 (BO), AL23.1 (BI)
unnamed: AL22.4 (DO), AL23.2 (DI)
unnamed: AL23.5 (BO), AL24.1 (BI)
unnamed: AL23.4 (DO), AL24.2 (DI)
unnamed: D14.2, R19.2
unnamed: LED1.1 (-), R21.1
unnamed: LED1.2 (-), R22.1
unnamed: LED1.3 (-), R20.1

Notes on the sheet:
Vf = 2.2V If = 20ma (3.3 - 2.2)/.02 = 55 ohms

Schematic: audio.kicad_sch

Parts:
BUZZER1: MLT-5020; BUZ-SMD_L5.0-W5.5-P4.60; LCSC Part C94598
Q5: DTC114E; DTC114EE; LCSC C94400
R42: 27Ω; R_0402_1005Metric
RV1: 1000Ω; Potentiometer_Bourns_3296W_Vertical; LCSC C57089

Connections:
+3.3V: RV1.1; also elsewhere on the board
/BuzzerMid: Q5.1 (B); also elsewhere on the board
GND: Q5.2 (E); also elsewhere on the board
unnamed: BUZZER1.1 (+), R42.2
unnamed: BUZZER1.2 (-), Q5.3 (C)
unnamed: R42.1, RV1.2

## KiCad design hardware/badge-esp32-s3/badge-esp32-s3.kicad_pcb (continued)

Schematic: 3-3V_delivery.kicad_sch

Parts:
C3, C4: 1uF; C_0402; Voltage Rated 25V; Tolerance ±10%; Part CL05A105KA5NQNC; LCSC C52923
C17, C27: 10uF; C0805; Manufacturer Part EMK212BJ106KG-T; LCSC Part Name 10uF ±10% 16V
C25, C34: 100nF; C_0402; Voltage Rated 16V; Tolerance ±10%; Part CL05B104KO5NNNC; LCSC C1525
C28, C37: TMK107BBJ106MA-T; C0603; LCSC Part C386081
C29, C30, C31: 22uF; C0805; Manufacturer Part MSASE21GBB5226MTNA01; LCSC Part Name 旧型号：EMK212BBJ226MG-T 22uF ±20% 16V
D1: Red; D_0603; Part KT-0603R; LCSC C2286
D13: SMAJ7.0A; SMA_L4.5-W2.6-LS5.1-RD; Manufacturer Part SMAJ7.0A; LCSC Part Name 单向TVS 7V截止 峰值脉冲电流：33.3A
L3: XGL4020-152MEC; IND-SMD_L4.0-W4.0_XEL4020; LCSC Part C7417180
Q4: HL2301A; Q_SOT-23; Part HL2301A; LCSC C7420344
Q7: AO3424; SC-59-3_L2.9-W1.6-P0.95-LS2.9-BR; LCSC Part C475606
R2: 5.1kΩ; R_0402; Overload Voltage (Max) 50V; Tolerance ±1%; Part 0402WGF5101TCE; LCSC C25905
R41: 150kΩ; R_0402; Overload Voltage (Max) 50V; Tolerance ±1%; Part 0402WGF1503TCE; LCSC C25755
R44, R53: 100kΩ; R_0402; Overload Voltage (Max) 50V; Tolerance ±1%; Part 0402WGF1003TCE; LCSC C25741
R46: 47kΩ; R_0402; Overload Voltage (Max) 50V; Tolerance ±1%; Part 0402WGF4702TCE; LCSC C25792
R54: 10kΩ; R_0402; Overload Voltage (Max) 50V; Tolerance ±1%; Part 0402WGF1002TCE; LCSC C25744
U2: TPS630701RNMR; VQFN-HR-15_L3.0-W2.5-P0.50-BL_TPS63070RNMR; LCSC Part C2876599
U8: TLV75733PDBVR; SOT-23-5_L2.9-W1.6-P0.95-LS2.8-BL; LCSC Part C485517

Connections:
+3.3V: C4.1, Q7.1 (G), R2.1, U8.5 (OUT); also elsewhere on the board
/5V_stable: C29.2, C30.2, C31.2, C37.2, D13.1 (K), R53.1, U2.5 (FB), U2.7 (VOUT), U2.8 (VOUT); also elsewhere on the board
/BatteryVoltage: C34.1, R41.2, R46.1; also elsewhere on the board
/VBATT: Q4.2 (S), R44.1; also elsewhere on the board
GND: C3.2, C4.2, C17.1, C25.2, C27.1, C28.1, C29.1, C30.1, C31.1, C34.2, C37.1, D1.1, D13.2 (A), Q7.2 (S), R46.2, U2.4 (GND), U2.6 (FB2), U2.10 (PGND), U2.15 (VSEL), U8.2 (GND); also elsewhere on the board
unnamed: D1.2, R2.2
unnamed: Q4.3 (D), R41.1
unnamed: Q4.1 (G), Q7.3 (D), R44.2
unnamed: R54.2, U2.1 (PS/SYNC), U2.14 (EN)
unnamed: L3.1, U2.11 (L1)
unnamed: L3.2, U2.9 (L2)
unnamed: R53.2, U2.2 (PG)
unnamed: C25.1, U2.3 (VAUX)
PWR_RAW: C3.1, C17.2, C27.2, C28.2, R54.1, U2.12 (VIN), U2.13 (VIN), U8.1 (IN), U8.3 (EN); also elsewhere on the board

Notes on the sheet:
Resistor divider: Divides by 4.2 to bring the battery voltage down to about 1V... perfect for the esp32 0dB ADC attenuation mode.

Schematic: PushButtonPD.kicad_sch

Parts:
C18: 1uF; C_0603; Voltage Rated 50V; Tolerance ±10%; Part CL10A105KB8NNNC; LCSC C15849
R27, R28: 10kΩ; R_0603; Overload Voltage (Max) 75V; Tolerance ±1%; Part 0603WAF1002T5E; LCSC C25804
SW4: TS665CJ; SW-TH_4P-L6.0-W6.0-P4.50-LS6.5; LCSC Part C393938

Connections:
+3.3V: SW4.2 (B); also elsewhere on the board
/LeftButtonMid: C18.1, R28.2; also elsewhere on the board
GND: C18.2, R27.2; also elsewhere on the board
unnamed: R27.1, R28.1, SW4.4 (D)

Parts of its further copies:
C19, C20, C21, C23: 1uF; C_0603; Voltage Rated 50V; Tolerance ±10%; Part CL10A105KB8NNNC; LCSC C15849
R29, R30, R31, R32, R33, R34, R37, R38: 10kΩ; R_0603; Overload Voltage (Max) 75V; Tolerance ±1%; Part 0603WAF1002T5E; LCSC C25804
SW5, SW6, SW7, SW9: TS665CJ; SW-TH_4P-L6.0-W6.0-P4.50-LS6.5; LCSC Part C393938

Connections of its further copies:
+3.3V: SW5.2 (B), SW6.2 (B), SW7.2 (B), SW9.2 (B); also elsewhere on the board
/BButtonMid: C21.1, R34.2; also elsewhere on the board
/DownButtonMid: C23.1, R38.2; also elsewhere on the board
/RightButtonMid: C20.1, R32.2; also elsewhere on the board
/UpButtonMid: C19.1, R30.2; also elsewhere on the board
GND: C19.2, C20.2, C21.2, C23.2, R29.2, R31.2, R33.2, R37.2; also elsewhere on the board
unnamed: R29.1, R30.1, SW5.4 (D)
unnamed: R31.1, R32.1, SW6.4 (D)
unnamed: R33.1, R34.1, SW7.4 (D)
unnamed: R37.1, R38.1, SW9.4 (D)

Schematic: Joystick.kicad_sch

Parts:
R23: YF16-FL7.2-B5KA(45-10)-R-A28; JOYTICK-TH_YF16-DFL7.2-B5KO-45-10-B5KO-55--RG-A22; LCSC Part C37323739

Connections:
+3.3V: R23.3, R23.4; also elsewhere on the board
/JoystickXMid: R23.2; also elsewhere on the board
/JoystickYMid: R23.5; also elsewhere on the board
GND: R23.1, R23.6, R23.7 (shell), R23.8 (shell), R23.9 (shell), R23.10 (shell); also elsewhere on the board

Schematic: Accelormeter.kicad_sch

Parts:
C10, C11: 100nF; C_0402; Voltage Rated 16V; Tolerance ±10%; Part CL05B104KO5NNNC; LCSC C1525
C26: 4.7uF; C_0603; Voltage Rated 16V; Tolerance ±10%; Part CL10A475KO8NNNC; LCSC C19666
R43, R45: 4.7kΩ; R_0402; Overload Voltage (Max) 50V; Tolerance ±1%; Part 0402WGF4701TCE; LCSC C25900
U18: MMA8452QR1_C11360; QFN-16_L3.0-W3.0-P0.50-TL_MMA8452QR1; LCSC Part C11360

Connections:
+3.3V: C10.1, C26.2, R43.1, R45.1, U18.1 (VDDIO), U18.14 (VDD); also elsewhere on the board
/GPIO41: R45.2, U18.6 (SDA); also elsewhere on the board
/GPIO42: R43.2, U18.4 (SCL); also elsewhere on the board
/Onboard Peripheral/Accelormeter/INT 1 (output to MCU, NN): U18.11 (INT1); also elsewhere on the board
/Onboard Peripheral/Accelormeter/INT 2 (output to MCU, NN): U18.9 (INT2); also elsewhere on the board
GND: C10.2, C11.2, C26.1, U18.5 (GND), U18.7 (SA0), U18.10 (GND), U18.12 (GND); also elsewhere on the board
unnamed: C11.1, U18.2 (BYP)

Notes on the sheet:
With SA0 Low, 001110 (0x1C) is the address, if high, its (0x1D)
Place 4.7uF Close to VDD

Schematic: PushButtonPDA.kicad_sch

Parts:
C22: 1uF; C_0603; Voltage Rated 50V; Tolerance ±10%; Part CL10A105KB8NNNC; LCSC C15849
R35, R36: 10kΩ; R_0603; Overload Voltage (Max) 75V; Tolerance ±1%; Part 0603WAF1002T5E; LCSC C25804
SW8: TS665CJ; SW-TH_4P-L6.0-W6.0-P4.50-LS6.5; LCSC Part C393938

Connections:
+3.3V: SW8.2 (B); also elsewhere on the board
/AButtonMid: C22.1, R36.2; also elsewhere on the board
GND: C22.2, R35.2; also elsewhere on the board
unnamed: R35.1, R36.1, SW8.3 (C)

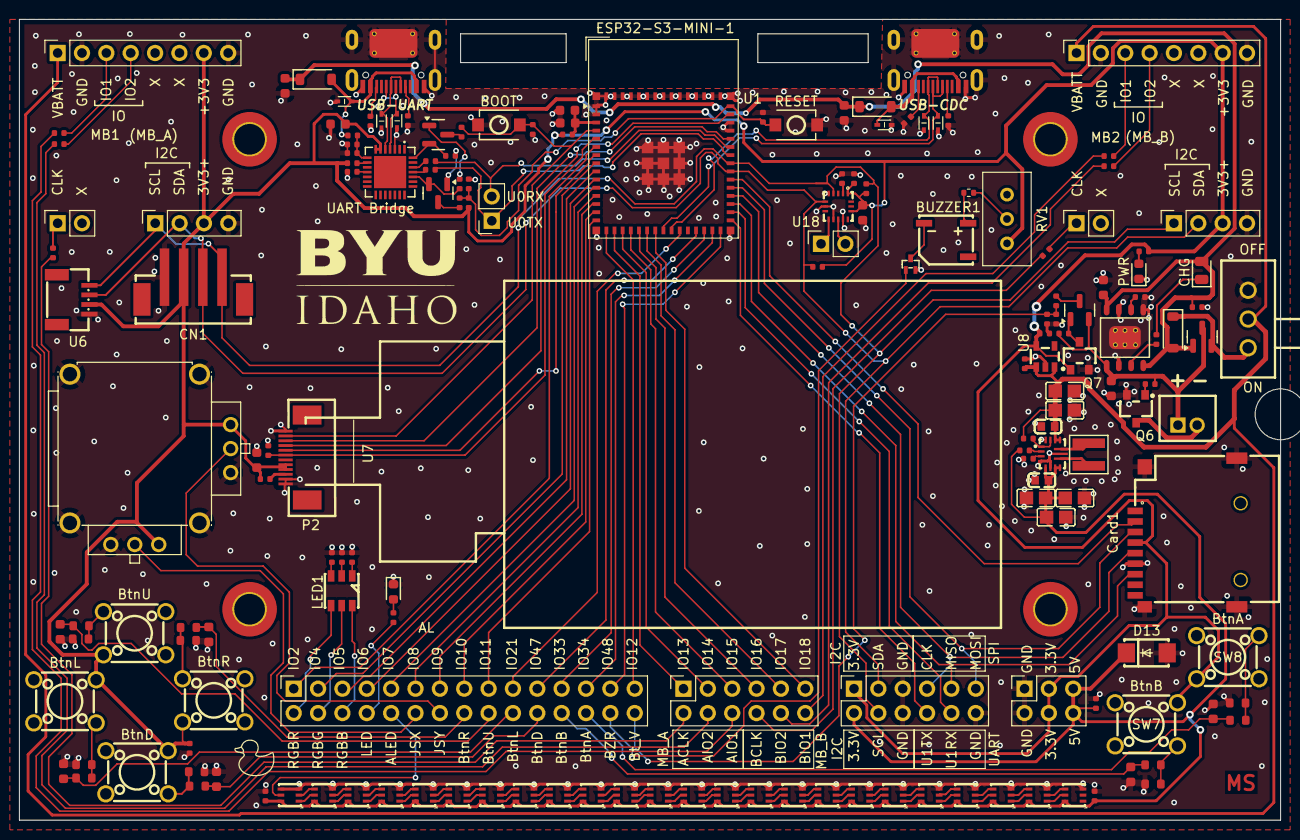
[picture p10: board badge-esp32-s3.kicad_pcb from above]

Board: 2 copper layers, 131.5 x 83.5 mm, 180 parts (0 on the bottom side), 169 nets.

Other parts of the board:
C5, C6: 10uF; C_0603
D2, D3, D4, D6, D7, D8: LESD5D5.0CT1G; SOD-523_L1.2-W0.8-LS1.6-BI
D5, D9: B0520W; D_SOD-123
J1, J2: Connector, USB-TYPE-C-16P; TYPE-C-SMD_HX-TYPE-C-16PIN
R3, R4, R5, R6: 5.1kΩ; R_0402

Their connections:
/ESP_USB+: D6.2, J2.A6 (D+), J2.B6 (D+); also elsewhere on the board
/ESP_USB-: D7.2, J2.A7 (D-), J2.B7 (D-); also elsewhere on the board
/UART Interface/USB_DN: D3.2, J1.A7 (D-), J1.B7 (D-); also elsewhere on the board
/UART Interface/USB_DP: D2.2, J1.A6 (D+), J1.B6 (D+); also elsewhere on the board
/USB_5V: C5.1, C6.1, D5.1, D9.1; also elsewhere on the board
/VBUS: D4.2, D5.2, J1.A9B4 (VBUS), J1.B9A4 (VBUS); also elsewhere on the board
/VBUSB: D8.2, D9.2, J2.A9B4 (VBUS), J2.B9A4 (VBUS)
GND: C5.2, C6.2, D2.1, D3.1, D4.1, D6.1, D7.1, D8.1, J1.A12B1 (GND), J1.B12A1 (GND), J1.S1 (SHIELD), J2.A12B1 (GND), J2.B12A1 (GND), J2.S1 (SHIELD), R3.2, R4.2, R5.2, R6.2; also elsewhere on the board
unnamed: J1.A5 (CC1), R3.1
unnamed: J1.B5 (CC2), R4.1
unnamed: J2.A5 (CC1), R5.1
unnamed: J2.B5 (CC2), R6.1

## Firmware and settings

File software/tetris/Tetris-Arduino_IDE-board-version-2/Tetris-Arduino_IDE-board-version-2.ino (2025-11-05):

/*
 * Tetris Game for ESP32-S3-Mini
 * 
 * Hardware:
 * - ST7789 240x320 TFT Display (rotated to 320x240)
 * - Analog buttons (Up, Down, Left, Right, A, B)
 * - RGB LED for piece color feedback
 * - Piezo buzzer for sound effects
 *
 * Libraries (using the Arduino IDE's Library Manager):
 * - Adafruit GFX Library
 * - Adafruit ST7735 and ST7789 Library
 */

#include <Adafruit_GFX.h>
#include <Adafruit_ST7789.h>
#include <SPI.h>

// ============================================================================
// PIN DEFINITIONS
// ============================================================================
const int PIN_X = 2;
const int PIN_Y = 1;
const int PIN_MINIBADGE_CLK = 12;
const int PIN_RIGHT = 13;
const int PIN_LEFT = 14;
const int PIN_DOWN = 15;
const int PIN_UP = 16;
const int PIN_B = 17;
const int PIN_A = 18;
const int PIN_SCL = 21;
const int PIN_RED = 38;
const int PIN_GREEN = 39;
const int PIN_BLUE = 40;
const int PIN_LED = 41;
const int PIN_BUZZER = 42;
const int PIN_TX = 43;
const int PIN_RX = 44;
const int PIN_SDA = 47;

// TFT Display pins
#define TFT_CS   33
#define TFT_RST  48
#define TFT_DC   37
#define TFT_MOSI 35
#define TFT_SCLK 36
#define TFT_MISO 34

// ============================================================================
// CONSTANTS
// ============================================================================
const int BUTTON_THRESHOLD = 4095 / 3;  // 1/3 of max ADC value
const int PWM_RESOLUTION_BITS = 10;
const int PWM_MAX_DUTY = 30;

// Game grid dimensions
const int GRID_WIDTH = 10;
const int GRID_HEIGHT = 18;
const int BLOCK_SIZE = 11;
const int GRID_OFFSET_X = 50;
const int GRID_OFFSET_Y = 15;

// Timing constants
const unsigned long BUTTON_DELAY = 150;
const unsigned long NORMAL_MOVE_DELAY = 500;
const unsigned long FAST_MOVE_DELAY = 50;
const unsigned long PAUSE_DEBOUNCE = 200;
const unsigned long LINE_FLASH_DELAY = 50;
const int LINE_FLASH_COUNT = 6;

// Scoring
const int POINTS_PER_LINE = 100;

// ============================================================================
// TETROMINO SHAPES
// ============================================================================
// Format: [piece_type][rotation][y][x]
const uint8_t SHAPES[7][4][4][4] = {
  // I piece
  {
    {{0,0,0,0}, {1,1,1,1}, {0,0,0,0}, {0,0,0,0}},
    {{0,0,1,0}, {0,0,1,0}, {0,0,1,0}, {0,0,1,0}},
    {{0,0,0,0}, {0,0,0,0}, {1,1,1,1}, {0,0,0,0}},
    {{0,1,0,0}, {0,1,0,0}, {0,1,0,0}, {0,1,0,0}}
  },
  // O piece (square - same for all rotations)
  {
    {{0,1,1,0}, {0,1,1,0}, {0,0,0,0}, {0,0,0,0}},
    {{0,1,1,0}, {0,1,1,0}, {0,0,0,0}, {0,0,0,0}},
    {{0,1,1,0}, {0,1,1,0}, {0,0,0,0}, {0,0,0,0}},
    {{0,1,1,0}, {0,1,1,0}, {0,0,0,0}, {0,0,0,0}}
  },
  // T piece
  {
    {{0,1,0,0}, {1,1,1,0}, {0,0,0,0}, {0,0,0,0}},
    {{0,1,0,0}, {0,1,1,0}, {0,1,0,0}, {0,0,0,0}},
    {{0,0,0,0}, {1,1,1,0}, {0,1,0,0}, {0,0,0,0}},
    {{0,1,0,0}, {1,1,0,0}, {0,1,0,0}, {0,0,0,0}}
  },
  // S piece
  {
    {{0,1,1,0}, {1,1,0,0}, {0,0,0,0}, {0,0,0,0}},
    {{0,1,0,0}, {0,1,1,0}, {0,0,1,0}, {0,0,0,0}},
    {{0,0,0,0}, {0,1,1,0}, {1,1,0,0}, {0,0,0,0}},
    {{1,0,0,0}, {1,1,0,0}, {0,1,0,0}, {0,0,0,0}}
  },
  // Z piece
  {
    {{1,1,0,0}, {0,1,1,0}, {0,0,0,0}, {0,0,0,0}},
    {{0,0,1,0}, {0,1,1,0}, {0,1,0,0}, {0,0,0,0}},
    {{0,0,0,0}, {1,1,0,0}, {0,1,1,0}, {0,0,0,0}},
    {{0,1,0,0}, {1,1,0,0}, {1,0,0,0}, {0,0,0,0}}
  },
  // J piece
  {
    {{1,0,0,0}, {1,1,1,0}, {0,0,0,0}, {0,0,0,0}},
    {{0,1,1,0}, {0,1,0,0}, {0,1,0,0}, {0,0,0,0}},
    {{0,0,0,0}, {1,1,1,0}, {0,0,1,0}, {0,0,0,0}},
    {{0,1,0,0}, {0,1,0,0}, {1,1,0,0}, {0,0,0,0}}
  },
  // L piece
  {
    {{0,0,1,0}, {1,1,1,0}, {0,0,0,0}, {0,0,0,0}},
    {{0,1,0,0}, {0,1,0,0}, {0,1,1,0}, {0,0,0,0}},
    {{0,0,0,0}, {1,1,1,0}, {1,0,0,0}, {0,0,0,0}},
    {{1,1,0,0}, {0,1,0,0}, {0,1,0,0}, {0,0,0,0}}
  }
};

// ============================================================================
// COLOR DEFINITIONS
// ============================================================================
// Display colors (16-bit RGB565 format)
const uint16_t COLORS[7] = {
  0x07FF,  // Bright Cyan
  0xFFE0,  // Bright Yellow
  0xF81F,  // Bright Magenta
  0x07E0,  // Bright Green
  0xF800,  // Bright Red
  0x001F,  // Bright Blue
  0xFD20   // Bright Orange
};

// RGB LED colors (8-bit per channel)
const uint8_t RGB_COLORS[7][3] = {
  {0, 255, 255},    // Cyan
  {255, 255, 0},    // Yellow
  {255, 0, 255},    // Magenta
  {0, 255, 0},      // Green
  {255, 0, 0},      // Red
  {0, 0, 255},      // Blue
  {255, 165, 0}     // Orange
};

// ============================================================================
// GLOBAL VARIABLES
// ============================================================================
Adafruit_ST7789 tft = Adafruit_ST7789(TFT_CS, TFT_DC, TFT_RST);

// Game grid (0 = empty, 1-7 = color index + 1)
uint8_t grid[GRID_HEIGHT][GRID_WIDTH];

// Current piece state
struct {
  int type;
  int rotation;
  int x;
  int y;
  int color;
} currentPiece;

// Previous piece position (for smooth redrawing)
struct {
  int x;
  int y;
  int rotation;
} prevPiece;

// Game state
struct {
  unsigned long lastMoveTime;
  unsigned long lastButtonTime;
  unsigned long moveDelay;
  int score;
  bool isOver;
  bool isPaused;
} gameState;

// ============================================================================
// UTILITY FUNCTIONS
// ============================================================================

/**
 * Set RGB LED color
 */
void setRgbColor(int r, int g, int b) {
  int dutyRed = map(r, 0, 255, 0, PWM_MAX_DUTY);
  int dutyGreen = map(g, 0, 255, 0, PWM_MAX_DUTY);
  int dutyBlue = map(b, 0, 255, 0, PWM_MAX_DUTY);
  
  analogWrite(PIN_RED, dutyRed);
  analogWrite(PIN_GREEN, dutyGreen);
  analogWrite(PIN_BLUE, dutyBlue);
}

/**
 * Check if analog button is pressed
 */
bool isButtonPressed(int pin) {
  return analogRead(pin) >= BUTTON_THRESHOLD;
}

// ============================================================================
// DRAWING FUNCTIONS
// ============================================================================

/**
 * Draw a single block on the display
 */
void drawBlock(int x, int y, uint16_t color) {
  int screenX = GRID_OFFSET_X + x * BLOCK_SIZE;
  int screenY = GRID_OFFSET_Y + y * BLOCK_SIZE;
  tft.fillRect(screenX, screenY, BLOCK_SIZE - 1, BLOCK_SIZE - 1, color);
}

/**
 * Draw the entire game grid
 */
void drawGrid() {
  for (int y = 0; y < GRID_HEIGHT; y++) {
    for (int x = 0; x < GRID_WIDTH; x++) {
      if (grid[y][x] > 0) {
        drawBlock(x, y, COLORS[grid[y][x] - 1]);
      } else {
        drawBlock(x, y, ST77XX_BLACK);
      }
    }
  }
}

/**
 * Draw the current falling piece
 */
void drawCurrentPiece() {
  for (int y = 0; y < 4; y++) {
    for (int x = 0; x < 4; x++) {
      if (SHAPES[currentPiece.type][currentPiece.rotation][y][x]) {
        int gridX = currentPiece.x + x;
        int gridY = currentPiece.y + y;
        if (gridY >= 0 && gridY < GRID_HEIGHT && gridX >= 0 && gridX < GRID_WIDTH) {
          drawBlock(gridX, gridY, COLORS[currentPiece.color]);
        }
      }
    }
  }
}

/**
 * Erase the previous piece position
 */
void erasePreviousPiece() {
  for (int y = 0; y < 4; y++) {
    for (int x = 0; x < 4; x++) {
      if (SHAPES[currentPiece.type][prevPiece.rotation][y][x]) {
        int gridX = prevPiece.x + x;
        int gridY = prevPiece.y + y;
        if (gridY >= 0 && gridY < GRID_HEIGHT && gridX >= 0 && gridX < GRID_WIDTH) {
          // Redraw the background (either empty or locked block)
          if (grid[gridY][gridX] > 0) {
            drawBlock(gridX, gridY, COLORS[grid[gridY][gridX] - 1]);
          } else {
            drawBlock(gridX, gridY, ST77XX_BLACK);
          }
        }
      }
    }
  }
}

/**
 * Draw the score display
 */
void drawScore() {
  tft.fillRect(200, 10, 110, 30, ST77XX_BLACK);
  tft.setCursor(200, 10);
  tft.setTextColor(ST77XX_WHITE);
  tft.setTextSize(2);
  tft.print("Score:");
  tft.setCursor(200, 30);
  tft.print(gameState.score);
}

/**
 * Draw the control key
 */
void drawControls() {
  tft.setTextSize(1);
  tft.setTextColor(ST77XX_CYAN);
  tft.setCursor(200, 60);
  tft.println("Controls:");
  tft.setTextColor(ST77XX_WHITE);
  tft.setCursor(200, 75);
  tft.println("L/R: Move");
  tft.setCursor(200, 90);
  tft.println("Up: Rotate");
  tft.setCursor(200, 105);
  tft.println("Dn: Drop");
  tft.setCursor(200, 120);
  tft.println("A: Pause");
  tft.setCursor(200, 135);
  tft.println("B: New Game");
}

/**
 * Draw the game border
 */
void drawBorder() {
  tft.drawRect(GRID_OFFSET_X - 2, GRID_OFFSET_Y - 2, 
               GRID_WIDTH * BLOCK_SIZE + 2, GRID_HEIGHT * BLOCK_SIZE + 2, 
               ST77XX_WHITE);
}

// ============================================================================
// GAME LOGIC FUNCTIONS
// ============================================================================

/**
 * Check if current piece collides with walls or other pieces
 */
bool checkCollision(int offsetX, int offsetY, int rotation) {
  for (int y = 0; y < 4; y++) {
    for (int x = 0; x < 4; x++) {
      if (SHAPES[currentPiece.type][rotation][y][x]) {
        int newX = currentPiece.x + x + offsetX;
        int newY = currentPiece.y + y + offsetY;
        
        // Check boundaries
        if (newX < 0 || newX >= GRID_WIDTH || newY >= GRID_HEIGHT) {
          return true;
        }
        
        // Check collision with placed blocks
        if (newY >= 0 && grid[newY][newX] > 0) {
          return true;
        }
      }
    }
  }
  return false;
}

/**
 * Lock the current piece into the grid
 */
void lockPiece() {
  for (int y = 0; y < 4; y++) {
    for (int x = 0; x < 4; x++) {
      if (SHAPES[currentPiece.type][currentPiece.rotation][y][x]) {
        int gridX = currentPiece.x + x;
        int gridY = currentPiece.y + y;
        if (gridY >= 0 && gridY < GRID_HEIGHT && gridX >= 0 && gridX < GRID_WIDTH) {
          grid[gridY][gridX] = currentPiece.color + 1;
        }
      }
    }
  }
}

/**
 * Clear completed lines and update score
 */
void clearLines() {
  int linesCleared = 0;
  
  for (int y = GRID_HEIGHT - 1; y >= 0; y--) {
    bool fullLine = true;
    
    // Check if line is full
    for (int x = 0; x < GRID_WIDTH; x++) {
      if (grid[y][x] == 0) {
        fullLine = false;
        break;
      }
    }
    
    if (fullLine) {
      linesCleared++;
      
      // Flash effect for cleared line
      for (int flash = 0; flash < LINE_FLASH_COUNT; flash++) {
        uint16_t flashColor = (flash % 2 == 0) ? 0x07E0 : 0x001F; // Green : Blue
        
        // Flash line on display
        for (int x = 0; x < GRID_WIDTH; x++) {
          drawBlock(x, y, flashColor);
        }
        
        // Flash RGB LED
        if (flash % 2 == 0) {
          setRgbColor(0, 255, 0);  // Green
        } else {
          setRgbColor(0, 0, 255);  // Blue
        }
        
        delay(LINE_FLASH_DELAY);
      }
      
      // Update score
      gameState.score += POINTS_PER_LINE;
      tone(PIN_BUZZER, 800, 100);
      
      // Move lines down
      for (int moveY = y; moveY > 0; moveY--) {
        for (int x = 0; x < GRID_WIDTH; x++) {
          grid[moveY][x] = grid[moveY - 1][x];
        }
      }
      
      // Clear top line
      for (int x = 0; x < GRID_WIDTH; x++) {
        grid[0][x] = 0;
      }
      
      y++; // Check this line again after moving down
    }
  }
  
  // Restore LED to current piece color after flashing
  if (linesCleared > 0) {
    setRgbColor(RGB_COLORS[currentPiece.color][0], 
                RGB_COLORS[currentPiece.color][1], 
                RGB_COLORS[currentPiece.color][2]);
  }
}

/**
 * Spawn a new piece at the top
 */
void spawnNewPiece() {
  currentPiece.type = random(7);
  currentPiece.color = currentPiece.type;
  currentPiece.rotation = 0;
  currentPiece.x = 3;
  currentPiece.y = 0;
  
  prevPiece.x = currentPiece.x;
  prevPiece.y = currentPiece.y;
  prevPiece.rotation = currentPiece.rotation;
  
  // Set RGB LED to match piece color
  setRgbColor(RGB_COLORS[currentPiece.color][0], 
              RGB_COLORS[currentPiece.color][1], 
              RGB_COLORS[currentPiece.color][2]);
  
  // Check for game over
  if (checkCollision(0, 0, 0)) {
    gameState.isOver = true;
  }
}

/**
 * Reset game to initial state
 */
void resetGame() {
  memset(grid, 0, sizeof(grid));
  gameState.score = 0;
  gameState.isOver = false;
  gameState.isPaused = false;
  gameState.moveDelay = NORMAL_MOVE_DELAY;
  
  tft.fillScreen(ST77XX_BLACK);
  drawBorder();
  spawnNewPiece();
  drawScore();
  drawControls();
}

/**
 * Handle game over state
 */
void handleGameOver() {
  tft.fillScreen(ST77XX_BLACK);
  tft.setCursor(80, 100);
  tft.setTextColor(ST77XX_RED);
  tft.setTextSize(3);
  tft.println("GAME");
  tft.setCursor(80, 130);
  tft.println("OVER");
  tft.setTextSize(2);
  tft.setCursor(60, 170);
  tft.setTextColor(ST77XX_WHITE);
  tft.print("Score: ");
  tft.println(gameState.score);
  tft.setTextSize(1);
  tft.setCursor(50, 200);
  tft.println("Press B for New Game");
  
  setRgbColor(255, 0, 0);
  tone(PIN_BUZZER, 200, 1000);
  
  // Wait for B button to restart
  while (true) {
    if (isButtonPressed(PIN_B)) {
      delay(200); // Debounce
      resetGame();
      return;
    }
    delay(50);
  }
}

/**
 * Toggle pause state
 */
void togglePause() {
  gameState.isPaused = !gameState.isPaused;
  
  if (gameState.isPaused) {
    // Show pause overlay
    tft.fillRect(80, 100, 120, 40, ST77XX_BLACK);
    tft.drawRect(79, 99, 122, 42, ST77XX_WHITE);
    tft.setCursor(100, 110);
    tft.setTextColor(ST77XX_YELLOW);
    tft.setTextSize(2);
    tft.println("PAUSED");
    setRgbColor(255, 255, 0); // Yellow for pause
  } else {
    // Clear pause overlay and restore display
    tft.fillRect(79, 99, 122, 42, ST77XX_BLACK);
    drawBorder();
    drawGrid();
    drawCurrentPiece();
    drawControls();
    setRgbColor(RGB_COLORS[currentPiece.color][0], 
                RGB_COLORS[currentPiece.color][1], 
                RGB_COLORS[currentPiece.color][2]);
  }
}

/**
 * Process player input
 */
void processInput() {
  unsigned long currentTime = millis();
  
  if (currentTime - gameState.lastButtonTime < BUTTON_DELAY) {
    return;
  }
  
  bool leftPressed = isButtonPressed(PIN_LEFT);
  bool rightPressed = isButtonPressed(PIN_RIGHT);
  bool downPressed = isButtonPressed(PIN_DOWN);
  bool upPressed = isButtonPressed(PIN_UP);
  bool aPressed = isButtonPressed(PIN_A);
  bool bPressed = isButtonPressed(PIN_B);
  
  // A button toggles pause
  if (aPressed) {
    togglePause();
    gameState.lastButtonTime = currentTime;
    delay(PAUSE_DEBOUNCE);
    return;
  }
  
  // B button starts new game
  if (bPressed) {
    delay(200);
    resetGame();
    return;
  }
  
  // Don't process other inputs if paused
  if (gameState.isPaused) {
    return;
  }
  
  bool pieceMoved = false;
  
  // Move left
  if (leftPressed && !checkCollision(-1, 0, currentPiece.rotation)) {
    prevPiece.x = currentPiece.x;
    prevPiece.y = currentPiece.y;
    prevPiece.rotation = currentPiece.rotation;
    currentPiece.x--;
    tone(PIN_BUZZER, 400, 50);
    gameState.lastButtonTime = currentTime;
    pieceMoved = true;
  }
  
  // Move right
  if (rightPressed && !checkCollision(1, 0, currentPiece.rotation)) {
    prevPiece.x = currentPiece.x;
    prevPiece.y = currentPiece.y;
    prevPiece.rotation = currentPiece.rotation;
    currentPiece.x++;
    tone(PIN_BUZZER, 450, 50);
    gameState.lastButtonTime = currentTime;
    pieceMoved = true;
  }
  
  // Fast drop
  if (downPressed) {
    gameState.moveDelay = FAST_MOVE_DELAY;
  } else {
    gameState.moveDelay = NORMAL_MOVE_DELAY;
  }
  
  // Rotate
  if (upPressed) {
    int newRotation = (currentPiece.rotation + 1) % 4;
    if (!checkCollision(0, 0, newRotation)) {
      prevPiece.x = currentPiece.x;
      prevPiece.y = currentPiece.y;
      prevPiece.rotation = currentPiece.rotation;
      currentPiece.rotation = newRotation;
      tone(PIN_BUZZER, 500, 50);
      gameState.lastButtonTime = currentTime;
      pieceMoved = true;
    }
  }
  
  // Redraw if piece moved
  if (pieceMoved) {
    erasePreviousPiece();
    drawCurrentPiece();
  }
}

/**
 * Update game state (piece falling)
 */
void updateGame() {
  if (gameState.isPaused) {
    return;
  }
  
  unsigned long currentTime = millis();
  
  if (currentTime - gameState.lastMoveTime > gameState.moveDelay) {
    if (!checkCollision(0, 1, currentPiece.rotation)) {
      // Move piece down
      prevPiece.x = currentPiece.x;
      prevPiece.y = currentPiece.y;
      prevPiece.rotation = currentPiece.rotation;
      currentPiece.y++;
      erasePreviousPiece();
      drawCurrentPiece();
    } else {
      // Piece has landed
      lockPiece();
      clearLines();
      spawnNewPiece();
      drawGrid();
      drawScore();
    }
    gameState.lastMoveTime = currentTime;
  }
}

// ============================================================================
// ARDUINO SETUP & LOOP
// ============================================================================

void setup() {
  Serial.begin(9600);
  Serial.println("Starting Tetris...");
  
  // Initialize display
  SPI.begin(TFT_SCLK, TFT_MISO, TFT_MOSI);
  tft.init(240, 320);
  tft.setRotation(1); // 320x240 landscape
  tft.fillScreen(ST77XX_BLACK);
  
  // Initialize RGB LED PWM
  analogWriteResolution(PIN_RED, PWM_RESOLUTION_BITS);
  analogWriteResolution(PIN_GREEN, PWM_RESOLUTION_BITS);
  analogWriteResolution(PIN_BLUE, PWM_RESOLUTION_BITS);
  
  // Initialize input pins
  pinMode(PIN_RIGHT, INPUT);
  pinMode(PIN_LEFT, INPUT);
  pinMode(PIN_DOWN, INPUT);
  pinMode(PIN_UP, INPUT);
  pinMode(PIN_B, INPUT);
  pinMode(PIN_A, INPUT);
  pinMode(PIN_BUZZER, OUTPUT);
  pinMode(PIN_LED, OUTPUT);
  
  // Seed random number generator
  randomSeed(analogRead(PIN_X));
  
  // Show splash screen
  tft.setCursor(60, 100);
  tft.setTextColor(ST77XX_GREEN);
  tft.setTextSize(3);
  tft.println("TETRIS");
  tft.setCursor(40, 140);
  tft.setTextSize(1);
  tft.setTextColor(ST77XX_WHITE);
  tft.println("Arrows: Move/Rotate");
  tft.setCursor(40, 155);
  tft.println("Down: Drop faster");
  tft.setCursor(40, 170);
  tft.println("A: Pause  B: New Game");
  
  delay(3000);
  
  // Initialize game
  tft.fillScreen(ST77XX_BLACK);
  resetGame();
  
  Serial.println("Game initialized!");
}

void loop() {
  if (gameState.isOver) {
    handleGameOver();
  }
  
  processInput();
  updateGame();
  
  delay(10);
}

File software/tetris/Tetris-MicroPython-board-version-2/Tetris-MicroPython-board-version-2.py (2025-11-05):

# NOTE: This program requires the following files from https://github.com/russhughes/st7789py_mpy
# st789py.py
# vga1_8x8.py

import machine
import st7789py as st7789
import vga1_8x8 as font
import utime
import random

# Pin definitions
TFT_SCLK = 36
TFT_MOSI = 35
TFT_MISO = 34
TFT_RST = 48
TFT_CS = 33
TFT_DC = 37
PIN_RIGHT = 13  # Analog button inputs
PIN_LEFT = 14
PIN_DOWN = 15
PIN_UP = 16
PIN_B = 17
PIN_A = 18
PIN_RED = 38
PIN_GREEN = 39
PIN_BLUE = 40
PIN_BUZZER = 42

# Game constants
GRID_WIDTH = 10
GRID_HEIGHT = 18
BLOCK_SIZE = 11
GRID_OFFSET_X = 50
GRID_OFFSET_Y = 15
BUTTON_THRESHOLD = 4095 // 3  # 1/3 of max ADC value
BUTTON_DELAY = 150  # ms
NORMAL_MOVE_DELAY = 500  # ms
FAST_MOVE_DELAY = 50  # ms
PAUSE_DEBOUNCE = 200  # ms
LINE_FLASH_DELAY = 50  # ms
LINE_FLASH_COUNT = 6
POINTS_PER_LINE = 100

# PWM settings for RGB LED
PWM_MAX_DUTY = 30

# Color definitions (RGB565, matching Arduino COLORS)
COLORS = [
    0x07FF,  # Cyan
    0xFFE0,  # Yellow
    0xF81F,  # Magenta
    0x07E0,  # Green
    0xF800,  # Red
    0x001F,  # Blue
    0xFD20   # Orange
]

# RGB LED colors (8-bit, matching Arduino RGB_COLORS)
RGB_COLORS = [
    (0, 255, 255),    # Cyan
    (255, 255, 0),    # Yellow
    (255, 0, 255),    # Magenta
    (0, 255, 0),      # Green
    (255, 0, 0),      # Red
    (0, 0, 255),      # Blue
    (255, 165, 0)     # Orange
]

# Tetromino shapes (matching Arduino SHAPES)
SHAPES = [
    # I
    [[[0,0,0,0], [1,1,1,1], [0,0,0,0], [0,0,0,0]],
     [[0,0,1,0], [0,0,1,0], [0,0,1,0], [0,0,1,0]],
     [[0,0,0,0], [0,0,0,0], [1,1,1,1], [0,0,0,0]],
     [[0,1,0,0], [0,1,0,0], [0,1,0,0], [0,1,0,0]]],
    # O
    [[[0,1,1,0], [0,1,1,0], [0,0,0,0], [0,0,0,0]],
     [[0,1,1,0], [0,1,1,0], [0,0,0,0], [0,0,0,0]],
     [[0,1,1,0], [0,1,1,0], [0,0,0,0], [0,0,0,0]],
     [[0,1,1,0], [0,1,1,0], [0,0,0,0], [0,0,0,0]]],
    # T
    [[[0,1,0,0], [1,1,1,0], [0,0,0,0], [0,0,0,0]],
     [[0,1,0,0], [0,1,1,0], [0,1,0,0], [0,0,0,0]],
     [[0,0,0,0], [1,1,1,0], [0,1,0,0], [0,0,0,0]],
     [[0,1,0,0], [1,1,0,0], [0,1,0,0], [0,0,0,0]]],
    # S
    [[[0,1,1,0], [1,1,0,0], [0,0,0,0], [0,0,0,0]],
     [[0,1,0,0], [0,1,1,0], [0,0,1,0], [0,0,0,0]],
     [[0,0,0,0], [0,1,1,0], [1,1,0,0], [0,0,0,0]],
     [[1,0,0,0], [1,1,0,0], [0,1,0,0], [0,0,0,0]]],
    # Z
    [[[1,1,0,0], [0,1,1,0], [0,0,0,0], [0,0,0,0]],
     [[0,0,1,0], [0,1,1,0], [0,1,0,0], [0,0,0,0]],
     [[0,0,0,0], [1,1,0,0], [0,1,1,0], [0,0,0,0]],
     [[0,1,0,0], [1,1,0,0], [1,0,0,0], [0,0,0,0]]],
    # J
    [[[1,0,0,0], [1,1,1,0], [0,0,0,0], [0,0,0,0]],
     [[0,1,1,0], [0,1,0,0], [0,1,0,0], [0,0,0,0]],
     [[0,0,0,0], [1,1,1,0], [0,0,1,0], [0,0,0,0]],
     [[0,1,0,0], [0,1,0,0], [1,1,0,0], [0,0,0,0]]],
    # L
    [[[0,0,1,0], [1,1,1,0], [0,0,0,0], [0,0,0,0]],
     [[0,1,0,0], [0,1,0,0], [0,1,1,0], [0,0,0,0]],
     [[0,0,0,0], [1,1,1,0], [1,0,0,0], [0,0,0,0]],
     [[1,1,0,0], [0,1,0,0], [0,1,0,0], [0,0,0,0]]]
]

# Initialize SPI
spi = machine.SPI(
    2,
    baudrate=60000000,
    polarity=1,
    phase=0,
    sck=machine.Pin(TFT_SCLK),
    mosi=machine.Pin(TFT_MOSI),
    miso=machine.Pin(TFT_MISO)
)

# Initialize display
tft = st7789.ST7789(
    spi,
    240, 320,
    reset=machine.Pin(TFT_RST, machine.Pin.OUT),
    cs=machine.Pin(TFT_CS, machine.Pin.OUT),
    dc=machine.Pin(TFT_DC, machine.Pin.OUT),
    rotation=3,  # Fixes upside-down text
    color_order=st7789.BGR  # Fix red/blue swap
)

# Initialize analog buttons (no pull-up needed for ADC)
adc_right = machine.ADC(machine.Pin(PIN_RIGHT))
adc_left = machine.ADC(machine.Pin(PIN_LEFT))
adc_down = machine.ADC(machine.Pin(PIN_DOWN))
adc_up = machine.ADC(machine.Pin(PIN_UP))
adc_a = machine.ADC(machine.Pin(PIN_A))
adc_b = machine.ADC(machine.Pin(PIN_B))

# Initialize RGB LED PWM
pwm_red = machine.PWM(machine.Pin(PIN_RED), freq=1000)
pwm_green = machine.PWM(machine.Pin(PIN_GREEN), freq=1000)
pwm_blue = machine.PWM(machine.Pin(PIN_BLUE), freq=1000)

# Initialize buzzer
buzzer = machine.PWM(machine.Pin(PIN_BUZZER), freq=1000, duty=0)

# Game state
grid = [[0] * GRID_WIDTH for _ in range(GRID_HEIGHT)]
game_state = {
    'last_move_time': 0,
    'last_button_time': 0,
    'move_delay': NORMAL_MOVE_DELAY,
    'score': 0,
    'is_over': False,
    'is_paused': False,
    'current_piece': {'type': 0, 'rotation': 0, 'x': 0, 'y': 0, 'color': 0},
    'prev_piece': {'x': 0, 'y': 0, 'rotation': 0}
}

def set_rgb_color(r, g, b):
    """Set RGB LED color (0-255 to PWM duty)."""
    duty_red = int((r / 255) * PWM_MAX_DUTY / 255 * 1023)
    duty_green = int((g / 255) * PWM_MAX_DUTY / 255 * 1023)
    duty_blue = int((b / 255) * PWM_MAX_DUTY / 255 * 1023)
    pwm_red.duty(duty_red)
    pwm_green.duty(duty_green)
    pwm_blue.duty(duty_blue)

def play_tone(freq, duration_ms):
    """Play a tone on the buzzer."""
    if freq > 0:
        buzzer.freq(freq)
        buzzer.duty(512)  # 50% duty cycle
    utime.sleep_ms(duration_ms)
    buzzer.duty(0)
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

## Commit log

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2025-06-18 Fixed Button, Added Joystick
    Button's extra resistor was removed
    Buttons were added to Onboard Peripheral sub sheet (all 6)
    Joystick was added to library + onboard Peripheral sub sheet in its own sub sheet.
    [Joystick.kicad_sch, PushButtonPB.kicad_sch, badge-esp32-s3.kicad_sch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]
2025-06-18 Added filter capacitor, upped PD to 100k, Removed 2 unused sheets
    Added a 100nF filter capacitor in parallel with the PD resistor (now 100k)
    Removed PushButton and PushButtonPB(a typo) subsheets as they are unused.
    [Joystick.kicad_sch, PushButton.kicad_sch, PushButtonPB.kicad_sch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]
2025-06-18 JST PH and JST SH headers completed
    Both subsheets are in exposed pins subsheet. I also had to make the symbols and footprints associated with each other.
    [JST-PH.kicad_sch, JST-SH.kicad_sch, exposed_pins.kicad_sch]
2025-06-19 Resistor Fix
    PD resistor 100k -> 47k
    [PushButtonPD.kicad_sch]
2025-06-20 Fully swap from WROOM to MINI MCU package
    [badge-esp32-s3.kicad_sch]
2025-06-24 Accelerometer
    I Ended up doing just the accelerometer, the others would have taken more pins etc.
    [Accelormeter.kicad_sch, onboard_peripheral.kicad_sch]
2025-06-24 Updated PD schematic
    Changed the button debounce schematic.
    [PushButtonPD.kicad_sch]
2025-06-24 Update badge-esp32-s3.kicad_sch
    GPIO pins labeled
    [badge-esp32-s3.kicad_sch]
2025-06-24 PD updated once again
    [PushButtonPD.kicad_sch]
2025-06-24 Add buzzer
    [audio.kicad_sch]
2025-06-24 Add new tri-color LED, library update
    [leds.kicad_sch]
2025-06-25 Switch on LDO enable pin
    [3-3V_delivery.kicad_sch]
2025-06-25 GPIO connections made (USB and External Pins yet to be done)
    [badge-esp32-s3.kicad_sch, leds.kicad_sch]
2025-06-25 Make sure joystick gets 3.3V power
    [onboard_peripheral.kicad_sch]
2025-06-25 Spelling error correction
    [JST-PH.kicad_sch]
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2025-06-26 add 3v3 to minibadge
    [badge-esp32-s3.kicad_sch]
2025-06-26 Fleshed out schematic with all exposed pins
    [3-3V_delivery.kicad_sch, Charging.kicad_sch, badge-esp32-s3.kicad_sch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]
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2025-06-26 Fix some DRC errors
    [Accelormeter.kicad_sch, PushButtonPD.kicad_sch, badge-esp32-s3.kicad_pcb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]
2025-06-26 Finish schematic, start placing parts on layout
    [badge-esp32-s3.kicad_pcb, badge-esp32-s3.kicad_sch, minibadge.kicad_sch]
2025-06-26 Moved header for exsample
    moved a component to show how to push to git
    [badge-esp32-s3.kicad_sch, minibadge.kicad_sch]
2025-06-26 Layout placed
    I've completed the PCB layout and am handing it off for trace routing. It's been a while since I last did this, so while I did my best to optimize placement, there may be areas where space is tight. Feel free to adjust component positioning as needed to make routing easier.
    Feedback is welcome—I wish I had more time to do the traces myself since that would be a valuable learning opportunit.
    [badge-esp32-s3.kicad_pcb]
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2025-06-27 Start routing stuff Used free route, so it's not ideal
    [badge-esp32-s3.kicad_pcb]
2025-06-27 errors and warnings resolved
    some warnings need to be addressed now and some errors are need to be rectified
    [badge-esp32-s3.kicad_pcb]
2025-06-27 Fix additional DRC errors (5 left)
    [badge-esp32-s3.kicad_pcb]
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2025-06-28 Finish beta layout for ordering
    [badge-esp32-s3.kicad_pcb]
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2025-07-10 Added buzzer and Joystick firmware tests
    [Joystick.ino, buzzerTest.ino]
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2025-07-11 Added firmware test
    Added two firmware test one that interfaces the buttons with the buzzer and one that shows different colors on the onboard RGB
    [Button_Buzzer_Test.ino]
2025-09-26 Oopsies, forgot to push my changes for final production (Spring 2025)
    [badge-esp32-s3.kicad_pcb]
2025-10-02 Add comments in PCB editor EXTREMELY SEVERE DRC VIOLATIONS AFTER MERGING
    [badge-esp32-s3.kicad_pcb]
2025-10-02 add connector with correct orientation for sceen
2025-10-06 Screen Port Fix
    Redo on the screen port fix on the most up-to-date board version.
    [badge-esp32-s3.kicad_pcb, display.kicad_sch]
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2025-10-11 update labels for changes
    [PushButtonPD.kicad_sch]
2025-10-11 Updated the pin number to be CD on the sd_card.
    [sd_card.kicad_sch]
2025-10-11 Updated the buzzer schematic and fixed the button traces.
2025-10-13 Updated the audio schematic and traces.
    [audio.kicad_sch, badge-esp32-s3.kicad_pcb]
2025-10-16 Fixed nested git repo issue in backups
    [badge-esp32-s3.kicad_pcb]
2025-10-16 Moved keypad and rerouted
    [badge-esp32-s3.kicad_pcb]
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2025-10-19 Updated the PCB to have the gpio jumper pins.
    [audio.kicad_sch, badge-esp32-s3.kicad_pcb, badge-esp32-s3.kicad_sch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]
2025-10-27 Consolidated the GPIO pins, communication pins, and power pins.
    [badge-esp32-s3.kicad_pcb, badge-esp32-s3.kicad_sch, exposed_pins.kicad_sch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]
2025-10-27 Moved the addressable LEDs to the top.
    [badge-esp32-s3.kicad_pcb]
2025-10-27 Swapped the RGB led pins.
    [badge-esp32-s3.kicad_sch, exposed_pins.kicad_sch, gpio_header_block.kicad_sch]
2025-10-27 Updated the buzzer to not use a jtag pin.
    [badge-esp32-s3.kicad_sch, exposed_pins.kicad_sch, gpio_header_block.kicad_sch]
2025-10-28 Started routing the traces.
    [badge-esp32-s3.kicad_pcb]
2025-10-29 Continued laying the traces.
    [badge-esp32-s3.kicad_pcb]
2025-10-29 Updated the messed up labels.
    [badge-esp32-s3.kicad_pcb]
2025-10-29 Updated the traces further.
    [badge-esp32-s3.kicad_pcb]
2025-10-29 Updated pins
    Updated pins and headers to avoid using internal flash SPI pins on schematic.
    [badge-esp32-s3.kicad_sch, gpio_header_block.kicad_sch]
2025-10-30 Fixed the errors in the schematic, and redid some label
    [badge-esp32-s3.kicad_pcb, badge-esp32-s3.kicad_sch]
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2025-10-31 finished routing the traces.
    [badge-esp32-s3.kicad_pcb]
2025-10-31 Updated the exposed gpio block.
    [badge-esp32-s3.kicad_sch, exposed_pins.kicad_sch]
2025-11-01 Fixed the LCSC Part numbers.
    [badge-esp32-s3.kicad_pcb]
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2025-11-01 Updated the layout of a some of the traces.
    [badge-esp32-s3.kicad_pcb]
2025-11-03 Updated Silkscreen
    Updated silkscreen on back of board to accommodate new pin mappings.
    [badge-esp32-s3.kicad_pcb]
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2025-11-05 Made 5V pins that connect to the +4V line. That is the name of the net coming off of the power switch.
    [badge-esp32-s3.kicad_sch, exposed_pins.kicad_sch]
2025-11-06 Updated the wiring for the 5V line to be connected to the +4V net. That is what it is named even though it is 4.5 ish volts.
    [badge-esp32-s3.kicad_sch, exposed_pins.kicad_sch, gpio_header_block.kicad_sch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]
2025-11-08 Started adding the circuitry for the 5V voltage booster.
    [3-3V_delivery.kicad_sch, badge-esp32-s3.kicad_sch]
2025-11-10 Added capacitors and inductors for the buck boost converter.
    [3-3V_delivery.kicad_sch, minibadge.kicad_sch]
2025-11-11 Added capacitors for the 5V booster circuit.
    [3-3V_delivery.kicad_sch, minibadge.kicad_sch]
2025-11-12 Updated the ESP32 Chip to N4R2
    [badge-esp32-s3.kicad_pcb]
2025-11-16 Added the buck-boost converter. The traces aren't all connected though.
    [3-3V_delivery.kicad_sch, badge-esp32-s3.kicad_pcb, badge-esp32-s3.kicad_sch]
2025-11-17 Update silkscreen
    Fixed BtnL and BtnR switch
    Changed silkscreen labels for buttons
    [badge-esp32-s3.kicad_pcb]
2025-11-18 Add the ground plane for the 5V regulation circuit.
    [badge-esp32-s3.kicad_pcb]
2025-11-20 Rotated U6, moved labels and renamed 3.3 to IO1
    [badge-esp32-s3.kicad_pcb]
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2025-11-22 Added boot and reset labels for buttons.
    [badge-esp32-s3.kicad_pcb]
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2025-11-22 I don't know what changed but I am pushing.
    [badge-esp32-s3.kicad_pcb]
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2025-11-22 Added thicker traces for the 5V circuit and added a TVS diode.
    [3-3V_delivery.kicad_sch, Charging.kicad_sch, badge-esp32-s3.kicad_pcb]
2025-11-24 Update Silkscreen
    Corrected header pin names, added button names, repositioned back-of-board pinmapping, added updated QR-Code
    [badge-esp32-s3.kicad_pcb]
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2025-11-24 Fixed the wiring for the 3.3V line.
    [exposed_pins.kicad_sch]
2025-11-24 Swapped the diode direction.
    [3-3V_delivery.kicad_sch, badge-esp32-s3.kicad_pcb]
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2026-01-27 changed joystick and fixed minibadge in the schematic
    [Joystick.kicad_sch, minibadge.kicad_sch]
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
